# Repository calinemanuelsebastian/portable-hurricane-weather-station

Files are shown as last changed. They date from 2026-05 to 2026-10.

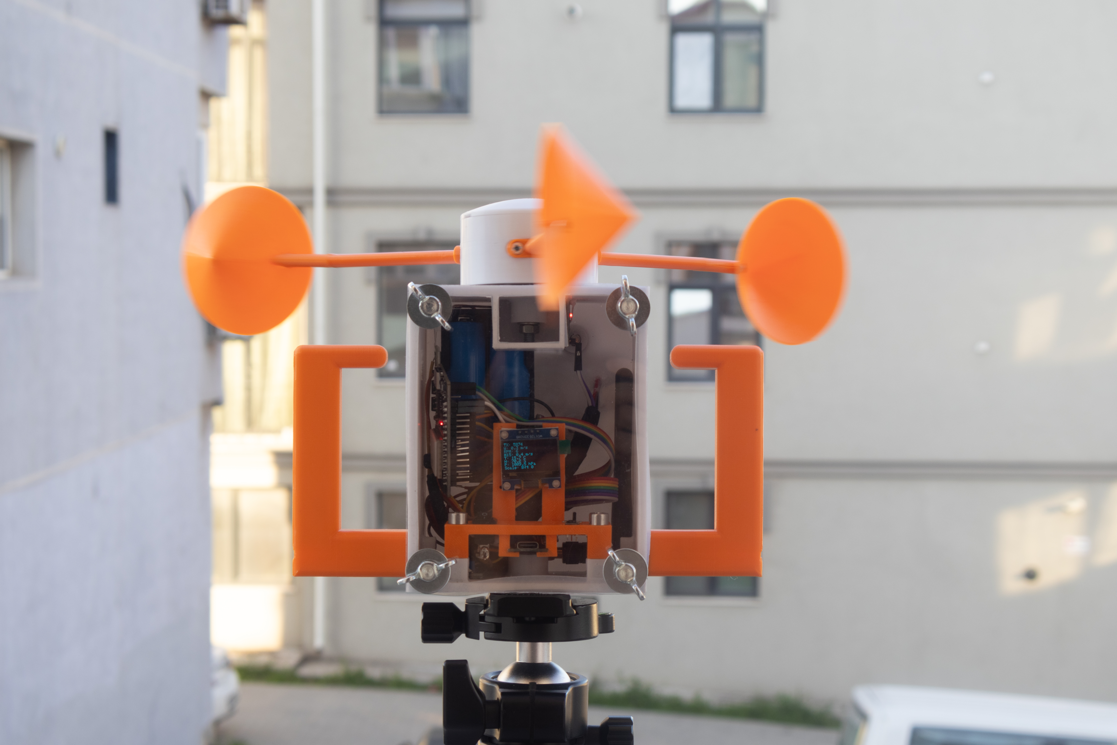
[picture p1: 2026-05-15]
images/IMG_7055-4.jpg

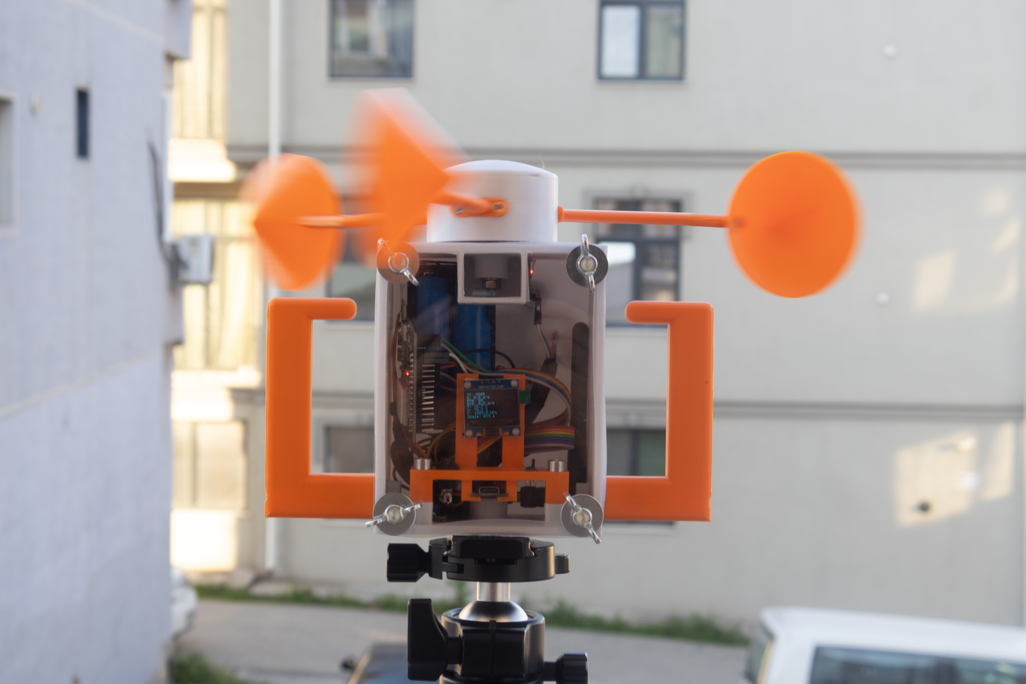
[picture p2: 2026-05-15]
images/IMG_7054-3.jpg

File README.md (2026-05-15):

# Portable Weather Station for Hurricane-Prone Island Environments

This repository contains the firmware, hardware documentation and development notes for a portable, low-cost meteorological monitoring system designed for local weather observation in hurricane-prone island environments.

The prototype measures wind speed, temperature, relative humidity and atmospheric pressure using an ESP32-based measurement unit, a custom Hall-effect cup anemometer, a DHT22 sensor and a BMP280 pressure sensor. Data are transmitted wirelessly to a central ESP32 station using nRF24L01 modules and published online through the ThingSpeak platform for remote visualisation.

## Links

Printables: https://www.printables.com/model/1719175-portable-esp32-weather-station-for-hurricane-prone 

ThingSpeak: https://thingspeak.mathworks.com/channels/3365147

## Project Status

This project is currently a functional prototype. The system has been tested for sensor acquisition, wireless transmission and online data publication. The wind-speed conversion algorithm is not callibrated against a reference anemometer.

## Main Features

- ESP32-based portable measurement unit
- Custom cup anemometer with Hall-effect pulse detection
- AHT22 temperature and relative humidity measurement
- BMP280 atmospheric pressure measurement
- nRF24L01 wireless communication between the portable unit and central station
- ESP32-based central station with Wi-Fi connection
- Online data publication through ThingSpeak
- OLED display for local data visualisation
- 3D-printed PETG enclosure and anemometer components

## System Architecture

The system is organised as follows:

```text
AHT20 + BMP280 + Hall-effect anemometer
                ↓
        ESP32 portable unit
                ↓
        nRF24L01 wireless link
                ↓
        ESP32 central station
                ↓
              Wi-Fi
                ↓
           ThingSpeak
                ↓
        Remote visualisation

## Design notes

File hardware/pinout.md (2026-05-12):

# Pinout

This document describes the wiring used by the current ESP32-based portable weather monitoring prototype.

The system has two electronic units:

1. `portable_station_esp32` – the measurement unit with sensors, OLED display, Hall-effect anemometer input and nRF24L01 transmitter;
2. `central_station_esp32` – the receiving unit with nRF24L01 receiver, Wi-Fi connection and ThingSpeak publication.

> Firmware reference: `portable_station_esp32_no_70kt_edge_filter.ino` and `central_station_esp32.ino`.

---

## 1. Portable station ESP32 pinout

### I2C bus

The portable station uses one I2C bus for the OLED display, AHT20 sensor and BMP280 pressure module.

| Function | ESP32 pin | Notes |
|---|---:|---|
| I2C SDA | GPIO 16 | Shared by OLED, AHT20 and BMP280 |
| I2C SCL | GPIO 17 | Shared by OLED, AHT20 and BMP280 |
| 3.3 V | 3V3 rail | Recommended supply for I2C modules |
| GND | GND | Common ground required |

Current I2C addresses used in the firmware:

| Device | Address | Notes |
|---|---:|---|
| AHT20 | `0x38` | Temperature and relative humidity |
| BMP280 | `0x77` | Change to `0x76` in firmware if the module uses that address |
| OLED display | `0x3C` | Change to `0x3D` in firmware if required |

Firmware line:

```cpp
Wire.begin(16, 17);
```

---

### AHT20 temperature and humidity sensor

| AHT20 pin | ESP32 / rail | Notes |
|---|---|---|
| VCC | 3.3 V | Use 3.3 V logic level with ESP32 |
| GND | GND | Common ground |
| SDA | GPIO 16 | I2C data |
| SCL | GPIO 17 | I2C clock |

---

### BMP280 pressure sensor

| BMP280 pin | ESP32 / rail | Notes |
|---|---|---|
| VCC / VIN | 3.3 V | Use 3.3 V if the board supports direct 3.3 V supply |
| GND | GND | Common ground |
| SDA | GPIO 16 | I2C data |
| SCL | GPIO 17 | I2C clock |

Current firmware address:

```cpp
#define BMP280_ADDRESS 0x77
```

If the sensor is not detected, try changing it to:

```cpp
#define BMP280_ADDRESS 0x76
```

---

### OLED display

| OLED pin | ESP32 / rail | Notes |
|---|---|---|
| VCC | 3.3 V | Use 3.3 V unless the OLED board specifically supports 5 V input |
| GND | GND | Common ground |
| SDA | GPIO 16 | I2C data |
| SCL | GPIO 17 | I2C clock |

Current firmware address:

```cpp
#define OLED_ADDRESS 0x3C
```

---

### KY-003 Hall-effect sensor for anemometer

The KY-003 Hall-effect sensor detects the three magnets installed on the rotating anemometer assembly.

| KY-003 pin | ESP32 / rail | Notes |
|---|---:|---|
| VCC | 3.3 V | Recommended for ESP32 logic safety |
| GND | GND | Common ground |
| OUT / Signal | GPIO 4 | Hall pulse input |

Firmware configuration:

```cpp
const int hallPin = 4;
pinMode(hallPin, INPUT_PULLUP);
attachInterrupt(digitalPinToInterrupt(hallPin), onMagnetDetected, FALLING);
```

Important notes:

- the firmware expects a falling edge when a magnet is detected;
- the current anemometer uses three magnets, so the firmware uses `pulsesPerRevolution = 3`;
- the current firmware uses only an electrical debounce gate for pulse filtering;
- no wind-speed-based 70 kt edge rejection threshold is used in the updated firmware.

---

### nRF24L01 module on portable station

| nRF24L01 pin | ESP32 pin / rail | Notes |
|---|---:|---|
| VCC | 3.3 V | Do not power the nRF24L01 from 5 V |
| GND | GND | Common ground |
| CE | GPIO 22 | Radio control pin |
| CSN / CS | GPIO 5 | SPI chip select |
| SCK | GPIO 18 | SPI clock |
| MISO | GPIO 19 | SPI MISO |
| MOSI | GPIO 23 | SPI MOSI |
| IRQ | Not connected | Not used in the current firmware |

Firmware configuration:

```cpp
#define CE_PIN    22
#define CSN_PIN    5
#define SCK_PIN   18
#define MISO_PIN  19
#define MOSI_PIN  23

SPI.begin(SCK_PIN, MISO_PIN, MOSI_PIN, CSN_PIN);
RF24 radio(CE_PIN, CSN_PIN);
const byte pipeAddress[6] = "RxAAA";
```

Power recommendation:

- place a capacitor of approximately 10 µF to 100 µF across the nRF24L01 VCC and GND pins;
- keep radio wiring short;
- use a stable 3.3 V supply, especially when the ESP32 and radio transmit at the same time.

---

## 2. Central station ESP32 pinout

The central station currently uses an ESP32 board, one nRF24L01 module, Wi-Fi and ThingSpeak publication. It does not use local environmental sensors in the current firmware.

### nRF24L01 module on central station

| nRF24L01 pin | ESP32 pin / rail | Notes |
|---|---:|---|
| VCC | 3.3 V | Do not power the nRF24L01 from 5 V |
| GND | GND | Common ground |
| CE | GPIO 22 | Radio control pin |
| CSN / CS | GPIO 5 | SPI chip select |
| SCK | GPIO 18 | SPI clock |
| MISO | GPIO 19 | SPI MISO |
| MOSI | GPIO 23 | SPI MOSI |
| IRQ | Not connected | Not used in the current firmware |

Firmware configuration:

```cpp
#define CE_PIN   22
#define CSN_PIN   5
#define SCK_PIN  18
#define MISO_PIN 19
#define MOSI_PIN 23

SPI.begin(SCK_PIN, MISO_PIN, MOSI_PIN, CSN_PIN);
RF24 radio(CE_PIN, CSN_PIN);
const byte pipeAddress[6] = "RxAAA";
```

---

## 3. Shared radio configuration

Both ESP32 boards must use the same nRF24L01 communication settings.

| Setting | Current value |
|---|---:|
| Pipe address | `RxAAA` |
| Data rate | `RF24_250KBPS` |
| Payload size | 32 bytes |
| Packet magic | `0x574E4431UL` / `WND1` |
| Packet version | `1` |

The packet structure must remain identical in both firmware files.

Current packet fields:

```cpp
struct __attribute__((packed)) SensorPacket {
  uint32_t magic;
  uint8_t  version;
  uint8_t  reserved;
  uint16_t seq;

  float temperatureC;
  float humidityPct;
  float seaLevelHpa;

  float windInstantMps;
  float windMeanMps;
  float windPeakMps;
};
```

The firmware checks that the payload is exactly 32 bytes:

```cpp
static_assert(sizeof(SensorPacket) == 32, "SensorPacket must be exactly 32 bytes");
```

If new fields are added, the packet size must be checked carefully because the nRF24L01 maximum payload size is 32 bytes.

---

## 4. ThingSpeak field mapping

The receiver firmware currently uploads the received values to ThingSpeak using the following field order:

| ThingSpeak field | Data uploaded by receiver firmware | Unit / meaning |
|---:|---|---|
| Field 1 | `temperatureC` | Temperature in °C |
| Field 2 | `humidityPct` | Relative humidity in % |
| Field 3 | `seaLevelHpa` | Sea-level equivalent pressure in hPa |
| Field 4 | `windInstantMps` | Instantaneous / displayed wind speed in m/s |
| Field 5 | `windMeanMps` | Mean wind speed over the transmission interval in m/s |
| Field 6 | `windPeakMps` | Peak / gust wind speed over the transmission interval in m/s |
| Field 7 | `beaufortMean` | Beaufort number calculated from mean wind speed |
| Field 8 | `sshwsEqMean` | Saffir-Simpson equivalent category calculated from mean wind speed |

Receiver firmware lines:

```cpp
ThingSpeak.setField(1, p.temperatureC);
ThingSpeak.setField(2, p.humidityPct);
ThingSpeak.setField(3, p.seaLevelHpa);
ThingSpeak.setField(4, p.windInstantMps);
ThingSpeak.setField(5, p.windMeanMps);
ThingSpeak.setField(6, p.windPeakMps);
ThingSpeak.setField(7, (long)beaufortMean);
ThingSpeak.setField(8, (long)sshwsEqMean);
```

Important: the ThingSpeak channel labels should match this field order. If the online channel is labelled differently, either relabel the ThingSpeak fields or change the receiver firmware field mapping.

---

## 5. Power wiring notes

### Portable station

The portable station is powered from two 18650 lithium-ion cells connected in series and protected by a 2S BMS.

Recommended power arrangement:

| Rail / module | Purpose |
|---|---|
| 2 × 18650 cells in series | Main battery pack |
| 2S BMS | Battery protection |
| Main switch | Turns portable unit on and off |
| MP1584EN buck converter | Regulated 3.3 V rail for sensors and nRF24L01 |
| MT3608 boost converter | 5 V supply for ESP32 development board, if used in the current build |

Important safety notes:

- verify all voltages with a multimeter before connecting the ESP32, sensors or radio modules;
- all modules must share a common ground;
- do not connect 5 V signals to ESP32 GPIO pins;
- the nRF24L01 must be powered from 3.3 V, not 5 V;
- lithium-ion cells require careful handling, correct polarity and a suitable BMS/charging arrangement.

### Central station

The central station can be powered from USB or a stable 5 V supply suitable for the ESP32 development board. The nRF24L01 module must still be supplied from 3.3 V.

---

## 6. Quick wiring checklist

Before powering the system:

- check battery polarity;
- check 3.3 V and 5 V rails with a multimeter;
- check that all grounds are connected together;
- check that the nRF24L01 modules receive 3.3 V only;
- check that SDA and SCL are connected to GPIO 16 and GPIO 17 on the portable station;
- check that both nRF24L01 modules use the same CE, CSN, SCK, MISO and MOSI wiring;
- check that the KY-003 output is connected to GPIO 4;
- check that the ThingSpeak field labels match the receiver firmware mapping;
- check that the packet structure is identical in both firmware files.

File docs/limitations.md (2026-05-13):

# Limitations

## Prototype status

This project is currently a functional prototype. It has been developed to demonstrate local meteorological data acquisition, wireless transmission and online visualisation. It is not a certified meteorological instrument and should not be used as a replacement for official weather stations.

## Wind-speed accuracy

The anemometer uses a custom mechanical design and a Hall-effect pulse detection system. The current wind-speed conversion algorithm is provisional and has not yet been calibrated against a reference anemometer.

Main limitations:

- the calibration factor is still experimental;
- rotor geometry affects the wind-speed conversion;
- friction, bearing quality and rotor balance may influence measurements;
- low wind speeds may be affected by starting friction;
- strong gusts may require further testing;
- the current algorithm requires calibration and characterisation under controlled conditions;
- the firmware currently uses an electrical debounce gate for Hall-sensor pulse detection, but no wind-speed-based edge rejection threshold is applied.

## Sensor limitations

The AHT20 and BMP280 sensors are suitable for prototype-level environmental monitoring, but the readings may be affected by enclosure placement, direct sunlight, ventilation and thermal influence from nearby electronics.

Possible sources of error include:

- insufficient airflow around the temperature and humidity sensor;
- heating from the ESP32 or voltage regulators;
- lack of radiation shielding;
- pressure reduction errors if altitude is not set correctly;
- sensor drift over time.

## Pressure correction limitations

The firmware converts pressure readings to sea-level equivalent pressure using a configured altitude value. If the altitude value is incorrect or left unchanged for a different deployment location, the reported sea-level pressure may be inaccurate.

For more reliable pressure reporting, future versions should:

- set the deployment altitude accurately;
- document the altitude used during each test;
- compare pressure readings with a reference instrument;
- allow altitude configuration without modifying the firmware.

## Enclosure limitations

The enclosure is made from 3D-printed PETG and uses a plexiglass front panel with a silicone gasket. Component ingresses are sealed with hot-melt adhesive.

This provides basic prototype-level protection, but the enclosure is not formally IP-rated.

Further improvements are needed for:

- long-term rain exposure;
- salt-air environments;
- UV exposure;
- corrosion protection;
- cable gland sealing;
- mechanical impact resistance;
- hurricane-level wind and debris conditions.

## Communication limitations

The current version uses nRF24L01 modules for communication between the portable station and the central station.

Limitations include:

- limited range compared with LoRa-based solutions;
- possible interference in the 2.4 GHz band;
- reduced performance through walls or obstacles;
- dependency on correct antenna positioning;
- possible packet loss in unfavourable conditions;
- no quantified packet-loss, range or reliability measurements have been performed yet;
- the transmitted packet is currently designed to fit within the nRF24L01 payload limit, so future changes to the packet structure should be checked carefully.

Future versions may use SX1278 LoRa modules or ESP32 boards equipped with LoRa transceivers for improved range and robustness.

## Power limitations

The portable unit uses two 18650 lithium-ion cells. Battery autonomy has not yet been fully tested under long-term outdoor operation.

The current documented wiring also includes a dedicated switch between the BMS/power distribution output and the input of the 3.3 V DC-DC converter. This allows the 3.3 V peripheral rail to be switched independently, but it also requires careful operation if the ESP32 5 V supply remains active.

Power-related limitations include:

- unknown long-term battery life;
- reduced capacity in cold or harsh conditions;
- possible voltage drops under load;
- charging system requiring further testing;
- lack of integrated solar charging in the current version;
- possible unintended back-powering of peripheral modules if the ESP32 is powered while the switched 3.3 V rail is off.

## Online publication limitations

The central station depends on Wi-Fi access and the availability of the ThingSpeak platform. If internet connectivity is lost, online visualisation may be interrupted.

Possible limitations include:

- dependency on Wi-Fi coverage at the central station;
- dependency on the ThingSpeak platform;
- interruption of online visualisation during internet outages;
- possible mismatch between firmware field order and ThingSpeak channel labels if the channel is not configured consistently.

Possible improvements include:

- local data logging;
- offline storage during internet outages;
- automatic upload after reconnection;
- configurable update intervals;
- alert thresholds for dangerous wind speeds or pressure drops.

## Testing limitations

The current tests focused on functional operation, not on formal validation.

The prototype has been tested for:

- sensor reading;
- OLED display;
- Hall sensor pulse detection;
- wireless transmission;
- reception by the central station;
- online publication through ThingSpeak.

The prototype has not yet been fully tested for:

- calibrated measurement accuracy;
- long-term outdoor reliability;
- battery autonomy;
- communication range;
- packet-loss rate;
- operation during heavy rain;
- resistance to severe wind;
- salt-air exposure;
- actual hurricane conditions.

## Intended use

The system is intended for:

- educational use;
- prototype development;
- experimental local weather observation;
- community-level awareness;
- research and demonstration purposes.

The system is not intended for:

- official meteorological reporting;
- navigation safety decisions;
- emergency warnings without independent verification;
- certified disaster-response operations.

## Future improvements

Recommended future developments include:

- calibration against a reference anemometer;
- comparison with certified temperature, humidity and pressure sensors;
- improved enclosure sealing;
- solar charging;
- longer-range communication;
- local data storage;
- improved power management;
- better radiation shielding for the temperature and humidity sensor;

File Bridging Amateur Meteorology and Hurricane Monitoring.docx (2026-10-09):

BRIDGING AMATEUR METEOROLOGY AND HURRICANE MONITORING: A PORTABLE WEATHER MONITORING SYSTEM FOR ISLAND COMMUNITIES

Emanuel-Sebastian CĂLIN

Constanța Maritime University

Coordinator: Lecturer PhD Alina Lucia BOȘTINĂ

Constanța Maritime University

Abstract

Hurricanes are extreme meteorological events with significant consequences for island communities, where geographical isolation, exposure to strong winds, and infrastructure vulnerability can intensify their social and operational impacts. In this context, real-time local weather monitoring can support preparedness, situational awareness, and emergency response. This study presents the design, implementation, and functional evaluation of a portable, low-cost meteorological monitoring system intended for hurricane-prone island environments. The prototype measures wind speed, temperature, relative humidity, and atmospheric pressure using a Hall sensor-based cup anemometer and an integrated AHT20 + BMP280 sensor module. The collected data are transmitted wirelessly to a central station and published online through the ThingSpeak platform, enabling remote access and visualisation. The system architecture, operating principles, and communication flow are described to show how localised meteorological data can be acquired and made available remotely. Functional tests confirmed the prototype's ability to collect, transmit, and publish meteorological data, indicating its potential as a complementary tool for local weather observation in areas exposed to severe weather events.

Keywords: hurricane-prone islands; disaster preparedness; portable weather station; low-cost meteorological instrumentation; remote data visualisation.

1. Introduction

Tropical cyclones (TCs), referred to as hurricanes in the Atlantic and eastern North Pacific basins, are among the most destructive meteorological hazards, affecting millions of people worldwide each year (1, 2). In these basins, a tropical cyclone is classified as a hurricane when its maximum sustained winds reach at least 64 knots, equivalent to approximately 119 km/h or 74 mph (3). Hurricane intensity is commonly described using the Saffir-Simpson Hurricane Wind Scale, which relates wind-speed categories to the potential for property damage and infrastructure disruption (4). Beyond extreme winds, tropical cyclones are multi-hazard events that may produce torrential rainfall, storm surges, flooding, and occasionally tornadoes, generating complex impacts on natural and human systems (2).

Island areas are particularly exposed to the effects of hurricanes because geographical isolation, limited land area, and dependence on critical infrastructure can increase vulnerability. Ports, airports, coastal roads, electricity networks, and communication systems are essential for evacuation, emergency response, and recovery, but they may also be severely affected during extreme weather events. In small island contexts, damage to a limited number of critical assets can disrupt emergency coordination and post-event recovery (8, 9).

Meteorological observation is a key component of early warning systems. The World Meteorological Organization identifies detection, monitoring, analysis, and forecasting as essential elements of effective multi-hazard early warning, together with risk knowledge, warning dissemination, and preparedness to respond (5). At the global scale, observing systems support weather analyses, forecasts, advisories, warnings, and climate monitoring (6). However, in isolated or resource-limited island environments, local observations may be spatially sparse or difficult to maintain, especially during severe weather events.

The atmospheric parameters selected for monitoring in this study are directly relevant to hurricane-prone environments. Wind speed is one of the defining characteristics of hurricane intensity and is essential for evaluating hazardous wind conditions. Atmospheric pressure variations may indicate the approach or development of low-pressure weather systems, while temperature and relative humidity contribute to the characterisation of local atmospheric conditions. These variables are consistent with WMO guidance on meteorological observation, including air temperature, atmospheric pressure, humidity, surface wind, and automatic weather stations (7).

Recent developments in embedded systems, wireless communication, and Internet of Things technologies have enabled compact and affordable weather stations for real-time environmental monitoring. Such systems do not replace certified meteorological stations, but they can provide useful supplementary observations for educational, research, community-based, or temporary field applications (10). In this context, the term amateur meteorology refers to non-certified, community-oriented, and low-cost observation activities that can complement, but not replace, official meteorological infrastructure. In this context, amateur meteorology refers to non-certified, community-oriented, and low-cost observation activities that can complement, but not replace, official meteorological infrastructure.

The aim of this paper is to present and functionally evaluate a portable, low-cost meteorological monitoring system designed to complement local weather observations and support situational awareness in hurricane-prone island environments.

2. Monitoring Needs in Hurricane-Prone Island Environments

Hurricane-prone island environments require monitoring approaches capable of providing timely, localised, and accessible meteorological information. The IPCC reports that small islands are increasingly affected by tropical cyclones, storm surges, heavy precipitation, sea-level rise, and related impacts across natural and human systems (8). Studies on Small Island Developing States also show that disaster vulnerability results from the interaction between physical exposure and local social, economic, and institutional conditions (9).

Although global and national observing networks provide indispensable information for forecasting and warning (5, 6, 7), local observations may be sparse in isolated or underserved areas, especially in small island contexts where exposure, remoteness, and infrastructure limitations increase vulnerability (8, 9). During severe weather events, permanent monitoring infrastructure may also be affected by power outages, communication disruptions, flooding, corrosion, or physical damage (5, 8, 9). Complementary local monitoring systems can therefore add practical value by increasing the number of observation points in vulnerable or underserved locations (5, 10).

For a local monitoring system to be useful, it should acquire relevant atmospheric variables and make them available to users without requiring direct access to the instrument. Wind speed, atmospheric pressure, temperature, and relative humidity provide a basic but important picture of the local atmospheric state and are among the standard variables considered in meteorological observation practice (7). Remote visualisation further supports situational awareness because users can observe changing conditions from a safer or more centralised location, which is consistent with the role of timely observation and communication in early warning systems and IoT-based monitoring approaches (5, 10).

In this paper, this monitoring need is addressed through a portable weather station designed to acquire wind speed, temperature, relative humidity, and atmospheric pressure data and publish them online. The system is intended as a complementary observation tool rather than an official source for warnings, certified measurements, or safety-critical decisions.

3. Design and Implementation of the Portable Weather Station

The proposed system was designed as a two-node architecture consisting of a portable measurement unit and a central receiving station. The measurement unit acquires local meteorological data, while the central station receives the data through a wireless link and publishes them online. The general data flow is presented in Figure 1.
Sensors
ESP32 (transmitter)
nRF24L01
ESP32 (receiver)
ThingSpeak

Figure 1. General architecture of the portable meteorological monitoring system

The portable unit is controlled by an ESP32 development board, selected because it provides sufficient processing capability for sensor reading, pulse counting, local display, and wireless communication in a compact format. In the documented prototype configuration, temperature and relative humidity are acquired using an AHT20 sensor, while atmospheric pressure is measured using a BMP280 module. The measured values are also shown on a small OLED display, which allows direct verification during testing and deployment.

Wind speed is measured using a custom cup anemometer. The rotating assembly includes three neodymium magnets placed at a constant distance from the centre of the shaft, while a KY-003 Hall-effect sensor module is fixed nearby. When the cups rotate, each magnet passes in front of the Hall sensor and generates a digital pulse. The ESP32 counts these pulses during the sampling interval and converts pulse frequency into a wind-speed value. At firmware level, the pulse frequency is converted into rotor speed using the configured number of pulses per revolution, after which the anemometer circumference and a provisional calibration factor are used to estimate wind speed. Since the relationship between rotor speed and actual wind speed depends on the anemometer geometry, the conversion algorithm is treated as a provisional functional implementation and requires calibration against a reference anemometer according to accepted meteorological measurement practice (7).

Wireless communication between the portable unit and the central station is currently implemented using nRF24L01 radio modules. The measurement unit sends the acquired values as data packets, while the receiving ESP32 decodes the information and prepares it for online publication. This communication solution was selected for the functional prototype because it is compact, low-cost, and suitable for short-range wireless data transmission, which is consistent with the use of low-cost components in IoT-based weather station prototypes (10). Future versions could use SX1278 LoRa modules or ESP32 boards equipped with LoRa transceivers where longer communication range is required.

The central station is built around a second ESP32 board connected to Wi-Fi. After receiving the values from the portable unit, it publishes the data to a dedicated ThingSpeak channel using the platform API. In the tested firmware, measurements were published at 15 s intervals, which was sufficient for remote visualisation during the functional evaluation. This arrangement separates local measurement from internet publication, allowing the portable station to be placed in the monitored area while the central station manages Wi-Fi connectivity and online data visualisation.

The portable unit is powered by two 18650 lithium-ion cells connected in series and protected by a battery management module. DC-DC converters provide the voltage levels required by the electronic modules, including a 3.3 V rail for low-voltage components and a 5 V line for the ESP32 development board. The enclosure, anemometer arms, and hub were manufactured using 3D-printed PETG parts. The front panel is made of plexiglass and fitted with a silicone gasket, while a second silicone gasket is placed between the external sensor pod and the main case to improve sealing at this interface. Cable and component ingresses were sealed using hot-melt adhesive for prototype-level protection. The modular structure of the system also allows future adaptation for different monitoring objectives by changing or extending the sensor set, communication module, or enclosure design without modifying the general architecture of the prototype.

4. Functional Evaluation and Results

The prototype was evaluated through functional tests intended to verify the complete data chain, from local measurement to online visualisation. The purpose of this stage was not to perform metrological calibration against certified instruments, but to confirm that the system can acquire data from the sensors, process the anemometer pulses, transmit the measurements wirelessly, and publish the results online. Formal meteorological measurement quality requires calibration, documented observing methods, and comparison with appropriate reference instruments (7).

During testing, the portable unit was powered from the 18650 battery pack and the measured values were displayed locally on the OLED screen. The AHT20 sensor was used to acquire temperature and relative humidity, while the BMP280 module provided pressure readings, which were converted in the firmware to sea-level equivalent pressure using a hard-coded altitude value. The cup anemometer was checked by rotating the rotor and observing the response of the Hall-effect sensor. Each passage of the magnets in front of the KY-003 module generated pulses that were counted by the ESP32 and converted by the software into a provisional wind-speed value.

The wireless communication link was tested using the nRF24L01 modules installed on the portable unit and on the central station. The measurement unit transmitted data packets containing the acquired meteorological values, while the receiving ESP32 decoded the information and forwarded it through Wi-Fi to the dedicated ThingSpeak channel. The online interface displayed separate charts for relative humidity, temperature, sea-level pressure, and wind speed, confirming that the measured data could be accessed remotely, as shown in Figure 2.

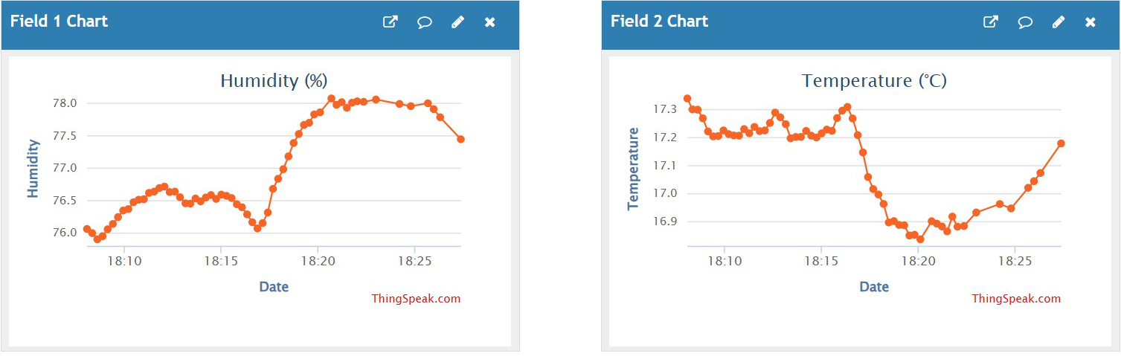
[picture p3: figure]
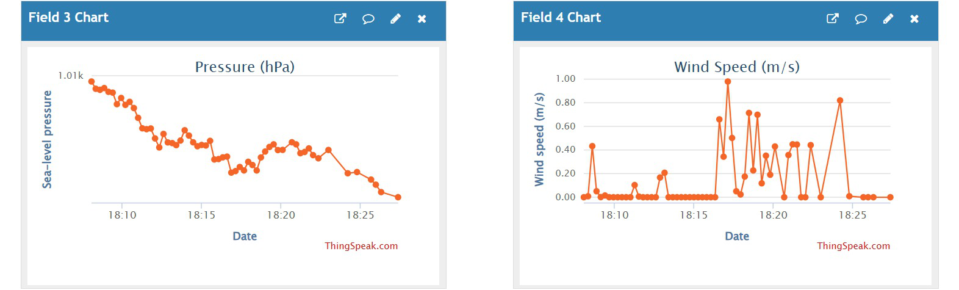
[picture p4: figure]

Figure 2. ThingSpeak dashboard during functional testing

The results confirm the functional operation of the prototype as an integrated portable weather station. The system was able to collect meteorological data, transmit them from the portable unit to the central station, and publish them online at 15s intervals during testing. The local OLED display also allowed direct monitoring of the measured values during operation, which is useful during testing and field deployment. Since the evaluation did not include comparison with calibrated reference instruments, numerical accuracy indicators such as measurement error, uncertainty, or deviation from reference values are not reported at this stage.

Several limitations were identified during this stage. First, the wind-speed conversion method has not yet been calibrated against a reference anemometer. The pressure correction also depends on the accuracy of the altitude value used in the firmware. Secondly, the tests focused on functional operation rather than long-term reliability, communication range, battery autonomy, or resistance to severe outdoor conditions. Although the PETG enclosure, plexiglass front panel, silicone gasket, and sealed ingresses provide adequate levels of protection, further improvements would be required before deployment in harsh hurricane-prone island environments, where exposure to extreme weather and infrastructure vulnerability are important concerns (8, 9).

5. Conclusions and Future Developments

This paper presented the design, implementation, and functional evaluation of a portable meteorological monitoring system intended for hurricane-prone island environments. The prototype was developed as a low-cost weather station capable of measuring wind speed, temperature, relative humidity, and atmospheric pressure. The system combines an ESP32-based measurement unit, a custom Hall-effect cup anemometer, an AHT20 + BMP280 sensor configuration, wireless transmission through nRF24L01 modules, and an ESP32-based central station connected to ThingSpeak for remote data visualisation.

The functional evaluation confirmed that the prototype can acquire meteorological data, display the values locally, transmit them wirelessly to the central station, and publish them online. These results demonstrate the correct operation of the main data chain, from sensor acquisition to remote visualisation. In this form, the system can be considered a practical complementary tool for local weather observation, especially in areas where permanent meteorological infrastructure is limited, difficult to access, or vulnerable during severe weather events (5, 8, 9).

At the same time, the prototype should not be regarded as a replacement for certified meteorological stations, since the current tests focused on functional operation rather than metrological accuracy, long-term reliability, or performance under extreme environmental conditions (7). In particular, the wind-speed measurement algorithm requires calibration against a reference anemometer, and the temperature, humidity, and pressure readings should be compared with reference instruments.

Future developments will focus on improving measurement performance, mechanical robustness, autonomy, and communication range. The wind-speed measurement system could be improved through a more rigid and better aligned shaft assembly, lower-friction bearings, improved rotor balancing, more precise magnet positioning, and calibration against a reference anemometer. The enclosure could also be improved through better sealing, corrosion-resistant connectors, cable glands, and extended outdoor testing under rain, salt-air, wind, and temperature variations.

The same modular platform could also be adapted for additional sensing applications. Depending on the use case, future versions could integrate air-quality sensors, ultraviolet radiation sensors, rain detection or rainfall measurement, soil-moisture sensors, battery-voltage monitoring, local data storage, or configurable alert thresholds. These extensions would allow the prototype to be used not only for hurricane-related monitoring, but also for broader environmental observation, educational fieldwork, temporary deployments, agricultural monitoring, or community-level situational awareness.

Although the prototype was developed for hurricane-prone island environments, the same communication concept could be extended to other isolated or difficult-to-access locations, such as remote maritime worksites, offshore facilities, natural or artificial islands, temporary field stations, or areas where direct access to main land-based infrastructure is limited. In such scenarios, longer-range radio modules such as SX1278, SX1262, or RFM96, possibly combined with intermediate relay nodes, would be more suitable than the short-range nRF24L01 link used in the current prototype.

Acknowledgements

The author would like to express sincere gratitude to Lecturer Alina Lucia BOȘTINĂ, PhD, for her guidance, support, and valuable feedback during the development of this paper and prototype. The author also thanks Diana-Iuliana MANEA, Lecturer Voicu Nicolae GROȘAN, PhD, and Marin OPREA, PhD, for their technical advice, encouragement, and support during the design, testing, and documentation of the portable weather monitoring system.

Project materials

The firmware, documentation, and 3D-printable parts are available through the project repository: https://github.com/calinemanuelsebastian/portable-hurricane-weather-station.

Bibliography

1. Geiger, T., Frieler, K. and Bresch, D. N. (2018), A global historical data set of tropical cyclone exposure (TCE-DAT), in „Earth System Science Data”, volume 10, issue 1, pp. 185-194, DOI: 10.5194/essd-10-185-2018.

2. World Meteorological Organization (2023), Tropical cyclones and their related hazards, Fact Sheet.

3. National Ocean Service, National Oceanic and Atmospheric Administration (n.d.), What is a hurricane?.

4. National Hurricane Center, National Oceanic and Atmospheric Administration (n.d.), Saffir-Simpson Hurricane Wind Scale.

5. World Meteorological Organization (2018), Multi-hazard Early Warning Systems: A Checklist, Outcome of the first Multi-hazard Early Warning Conference.

6. World Meteorological Organization (n.d.), Global Observing System (GOS).

7. World Meteorological Organization (2024), Guide to Instruments and Methods of Observation (WMO-No. 8), 2024 edition.

8. Mycoo, M., Wairiu, M., Campbell, D., Duvat, V., Golbuu, Y., Maharaj, S., Nalau, J., Nunn, P., Pinnegar, J. and Warrick, O. (2022), Small Islands, in „Climate Change 2022: Impacts, Adaptation and Vulnerability”, Contribution of Working Group II to the Sixth Assessment Report of the Intergovernmental Panel on Climate Change, Cambridge, Cambridge University Press.

9. Pelling, M. and Uitto, J. I. (2001), Small island developing states: natural disaster vulnerability and global change, in „Global Environmental Change Part B: Environmental Hazards”, 3(2), pag. 49-62, DOI: 10.1016/S1464-2867(01)00018-3.

10. Ioannou, K., Karampatzakis, D., Amanatidis, P., Aggelopoulos, V. and Karmiris, I. (2021), Low-cost automatic weather stations in the Internet of Things, in „Information”, 12(4), 146, DOI: 10.3390/info12040146.

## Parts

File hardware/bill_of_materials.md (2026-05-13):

# Bill of Materials

This bill of materials covers the current functional prototype of the portable ESP32-based weather monitoring system. The system consists of two main units:

1. **portable_station_esp32** — the portable measurement unit;
2. **central_station_esp32** — the receiving station connected to Wi-Fi and ThingSpeak.

> Note: the current firmware uses an **AHT20 + BMP280** configuration. If the physical module is changed, the firmware, documentation and ThingSpeak labels should be updated accordingly.

---

## 1. Control and communication components

### ESP32 development board
- **Quantity:** 2
- **Used for:** portable measurement unit and central receiving station
- **Notes:** one ESP32 reads the sensors and transmits data; the second ESP32 receives the data and publishes them online.

### nRF24L01 wireless module
- **Quantity:** 2
- **Used for:** wireless communication between the portable unit and the central station
- **Notes:** used in the current functional prototype.

### SX1278 LoRa module
- **Quantity:** 2
- **Status:** optional / future improvement
- **Notes:** may be used in future versions where longer communication range is required.

### ESP32 board with integrated LoRa transceiver
- **Quantity:** 2
- **Status:** optional / alternative configuration
- **Notes:** may be used in future versions to simplify the long-range communication architecture.

---

## 2. Sensors and display

### AHT20 sensor module
- **Quantity:** 1
- **Used for:** temperature and relative humidity measurement
- **Notes:** connected to the portable ESP32 through the I2C bus.

### BMP280 module
- **Quantity:** 1
- **Used for:** atmospheric pressure measurement
- **Notes:** connected to the portable ESP32 through the I2C bus. The firmware can use address `0x77` or `0x76`, depending on the physical module.

### KY-003 Hall-effect sensor module
- **Quantity:** 1
- **Used for:** anemometer pulse detection
- **Notes:** detects the passage of the magnets mounted on the rotating anemometer assembly.

### OLED display
- **Quantity:** 1
- **Used for:** local visualisation on the portable unit
- **Notes:** displays temperature, humidity, pressure, wind speed and system status information.

---

## 3. Anemometer assembly

### Neodymium magnets
- **Quantity:** 3
- **Used for:** Hall-effect pulse generation
- **Notes:** mounted on the rotating anemometer assembly. The firmware is currently configured for three pulses per revolution.

### 625 bearings
- **Quantity:** 2
- **Used for:** anemometer shaft support
- **Notes:** open bearings are preferred. In the prototype, 625ZZ bearings may be modified by removing the metal shields and cleaning the grease to reduce rotational resistance.

### M5 threaded rod or M5 screw
- **Quantity:** 1
- **Used for:** anemometer shaft assembly
- **Notes:** cut to the length required by the printed anemometer structure.

### PETG printed anemometer parts
- **Quantity:** several
- **Used for:** anemometer hub, arms and cup supports
- **Notes:** printed from PETG for better mechanical and environmental resistance than PLA.

---

## 4. Power supply components

### 18650 lithium-ion cells
- **Quantity:** 2
- **Used for:** portable unit power supply
- **Notes:** connected in series as a 2S battery pack.

### 2S BMS module
- **Quantity:** 1
- **Used for:** battery protection
- **Notes:** protects the two 18650 cells connected in series.

### Main power switch
- **Quantity:** 1
- **Used for:** main portable-station power control, if installed immediately after the BMS output
- **Notes:** use this switch to disconnect the complete portable unit from the battery supply if a full master on/off function is required.

### 3.3 V rail switch
- **Quantity:** 1
- **Used for:** switching the input of the 3.3 V DC-DC converter
- **Notes:** in the current documented wiring, this switch is placed between the BMS/power distribution positive output and the MP1584EN input. It controls the 3.3 V rail used by the AHT20, BMP280, OLED display, KY-003 Hall sensor and nRF24L01 module.

### MP1584EN step-down converter
- **Quantity:** 1
- **Used for:** regulated 3.3 V supply
- **Notes:** supplies low-voltage modules such as the AHT20, BMP280, OLED display, KY-003 and nRF24L01. Verify the output with a multimeter before connecting the modules.

### 5 V regulator / boost converter
- **Quantity:** 1
- **Used for:** 5 V ESP32 development-board supply, if the ESP32 is powered through VIN/5V
- **Notes:** choose a regulator suitable for the 2S lithium-ion input range. A fully charged 2S pack can reach approximately 8.4 V.

### Additional DC-DC converters
- **Quantity:** as required
- **Status:** optional
- **Notes:** useful for alternative power architectures, separate rails or charging experiments.

### USB cable / USB power adapter
- **Quantity:** as required
- **Used for:** programming and powering the ESP32 boards
- **Notes:** especially useful for the central receiving station.

### Solar charging module
- **Quantity:** 1
- **Status:** optional / future improvement
- **Notes:** may improve autonomy during outdoor deployment.

---

## 5. Enclosure and printed parts

### PETG printed enclosure
- **Quantity:** 1 complete set
- **Used for:** housing the portable measurement unit
- **Notes:** includes the main enclosure body and any internal supports.

### PETG printed internal supports
- **Quantity:** several
- **Used for:** mounting electronic modules inside the enclosure
- **Notes:** quantity depends on the final internal layout.

### PETG filament
- **Quantity:** approximately 1 kg
- **Used for:** printing the enclosure, hub, arms and supports
- **Notes:** required if the parts are printed locally.

### Plexiglass sheet
- **Quantity:** 1
- **Used for:** front panel
- **Notes:** allows visibility of the OLED display and internal layout.

### Silicone gasket material
- **Quantity:** 1
- **Used for:** front panel sealing
- **Notes:** placed between the plexiglass panel and the printed enclosure.

### Weatherproof cable glands
- **Quantity:** as required
- **Status:** optional / future improvement
- **Notes:** recommended for more robust outdoor use.

---

## 6. Mechanical fasteners and assembly hardware

### Threaded inserts
- **Quantity:** as required
- **Used for:** printed enclosure and mechanical fixing points
- **Notes:** use the sizes required by the final printed design.

### Screws, nuts and washers
- **Quantity:** as required
- **Used for:** enclosure, front panel, supports and anemometer assembly
- **Notes:** stainless steel or corrosion-resistant fasteners are recommended for humid or salt-air environments.

### Butterfly screws and wide washers
- **Quantity:** as required
- **Used for:** removable access points, such as the plexiglass front panel
- **Notes:** useful where repeated access to the internal electronics is needed.

---

## 7. Wiring and electrical assembly materials

### Wires and connectors
- **Quantity:** as required
- **Used for:** electrical connections
- **Notes:** Dupont wires, soldered wires, JST connectors or similar may be used. Soldered or locking connectors are preferred for field use.

### Header pins
- **Quantity:** as required
- **Used for:** module connections
- **Notes:** useful for ESP32, sensor modules and radio modules.

### Prototype PCB / perfboard
- **Quantity:** as required
- **Status:** optional
- **Notes:** useful for making the internal wiring cleaner and more reliable.

### Heat-shrink tubing
- **Quantity:** as required
- **Used for:** insulation and strain relief
- **Notes:** recommended for soldered joints and exposed conductors.

### Capacitor for nRF24L01 module
- **Quantity:** 1–2
- **Recommended value:** 10 µF to 100 µF
- **Used for:** stabilising the nRF24L01 power supply
- **Notes:** place the capacitor close to the nRF24L01 VCC and GND pins.

---

## 8. Adhesives, sealants and auxiliary materials

### Threadlocker, e.g. Loctite
- **Quantity:** as required
- **Used for:** preventing loosening of nuts and screws caused by vibration or rotation.

### Double-sided adhesive tape
- **Quantity:** as required
- **Used for:** temporary or semi-permanent mounting of lightweight internal components.

### Hot-melt adhesive or sealant
- **Quantity:** as required
- **Used for:** prototype-level sealing of cable and component ingresses.

### Silicone sealant
- **Quantity:** optional
- **Status:** future improvement
- **Notes:** may provide better sealing than hot-melt adhesive for outdoor use.

---

## 9. Optional data and autonomy improvements

### MicroSD card module
- **Quantity:** 1
- **Status:** optional / future improvement
- **Purpose:** local data logging during internet outages.

### Real-time clock module
- **Quantity:** 1
- **Status:** optional / future improvement
- **Purpose:** timestamping locally stored measurements.

### Battery voltage monitoring circuit
- **Quantity:** 1
- **Status:** optional / future improvement
- **Purpose:** monitoring battery level and improving power management.

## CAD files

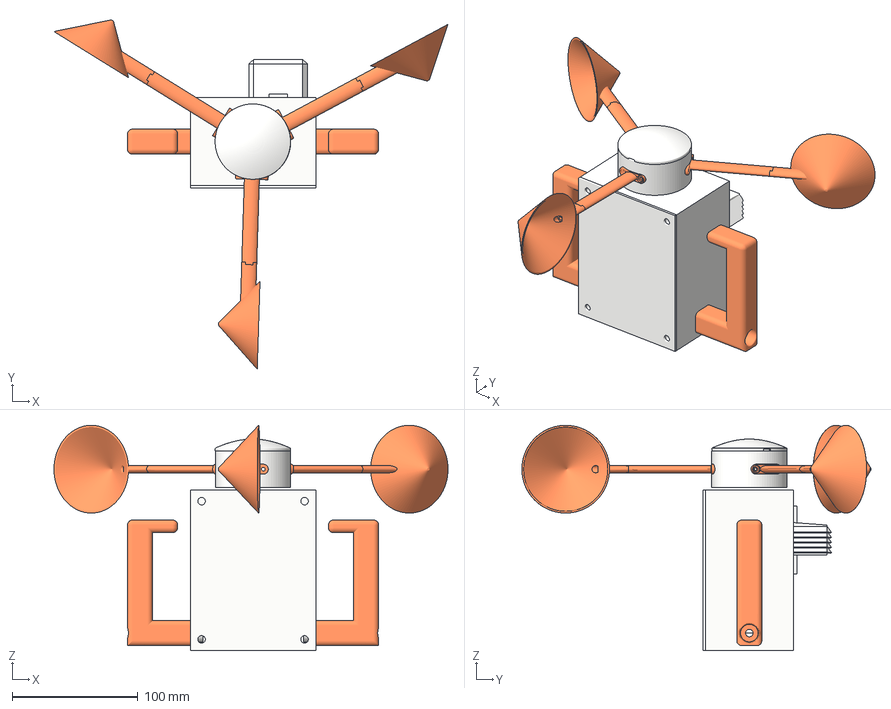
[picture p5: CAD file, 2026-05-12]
cad/printable_parts/portable_weather_station_cad_complete.3mf
313.7 x 278.1 x 179.4 mm
Accumulators
ESP32

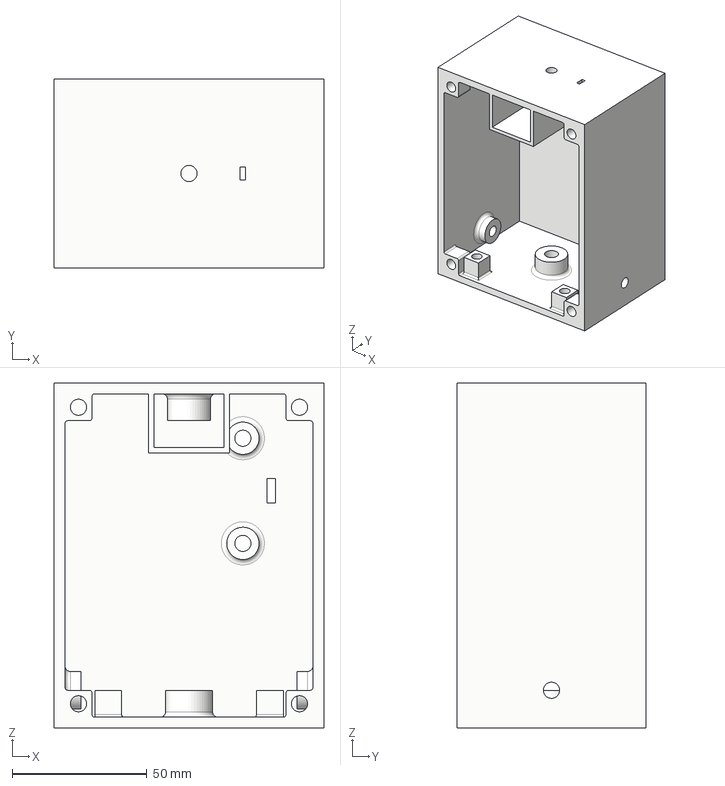
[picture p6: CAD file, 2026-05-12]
cad/printable_parts/Main body.step
100.0 x 70.0 x 128.0 mm

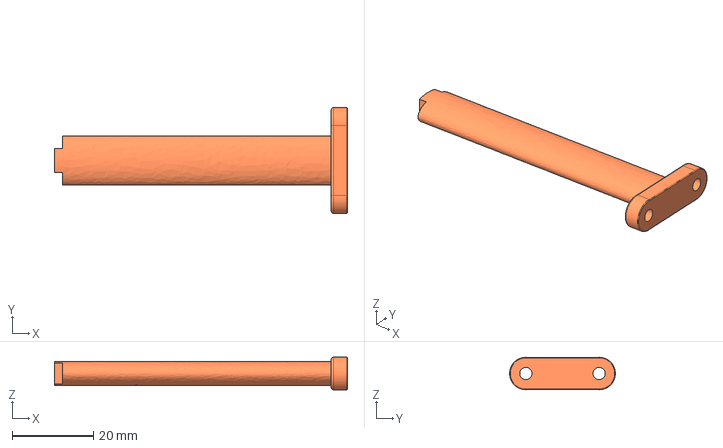
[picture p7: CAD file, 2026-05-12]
cad/printable_parts/Arm.step
72.0 x 26.0 x 8.00 mm

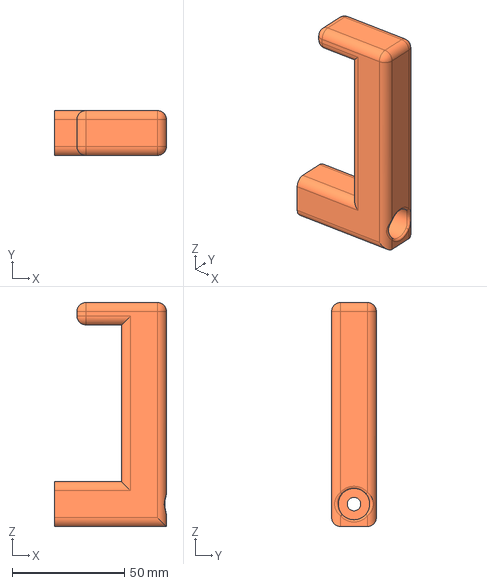
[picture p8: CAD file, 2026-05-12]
cad/printable_parts/Side handle.step
50.0 x 20.0 x 100.0 mm

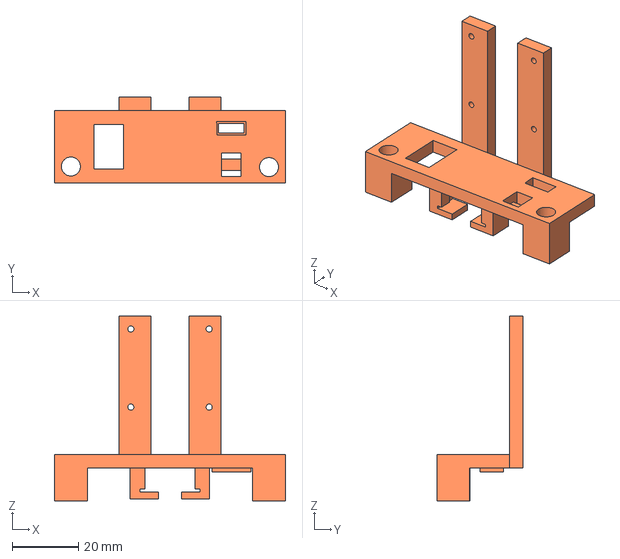
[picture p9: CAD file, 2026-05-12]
cad/printable_parts/Screen and buttons bracket.step
70.0 x 26.0 x 56.0 mm

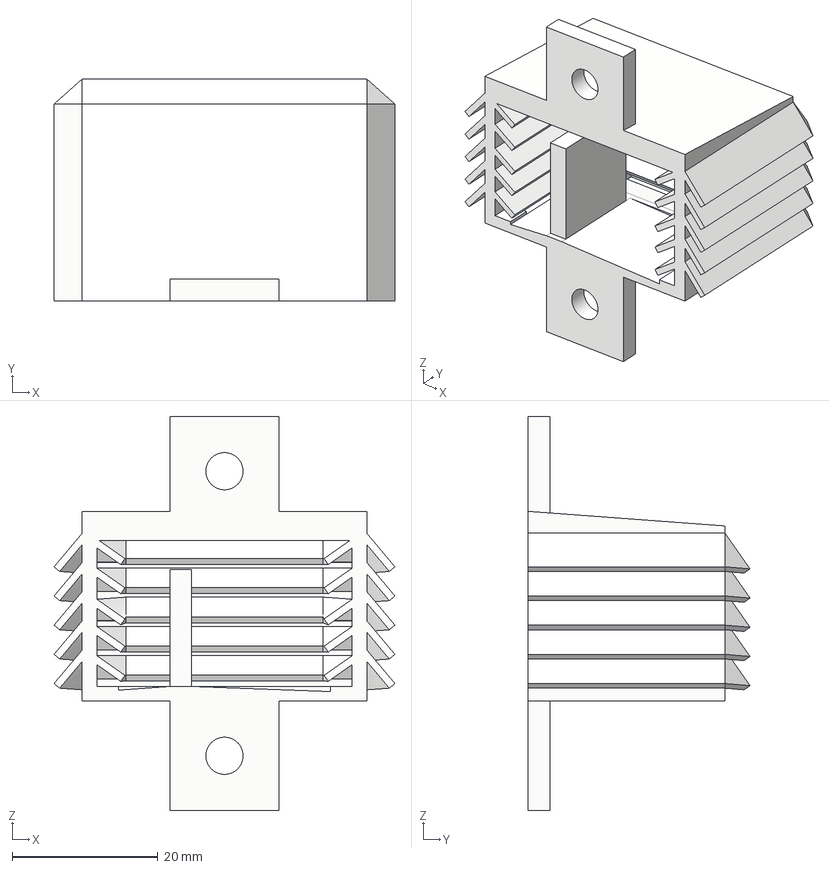
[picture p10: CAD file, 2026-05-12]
cad/printable_parts/Temperature sensor pod.step
46.7 x 30.4 x 54.0 mm

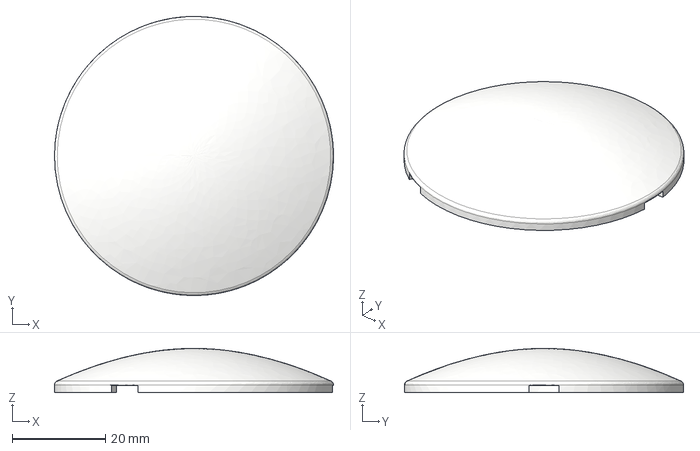
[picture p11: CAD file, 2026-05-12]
cad/printable_parts/Rotor cap.step
60.0 x 60.0 x 9.50 mm

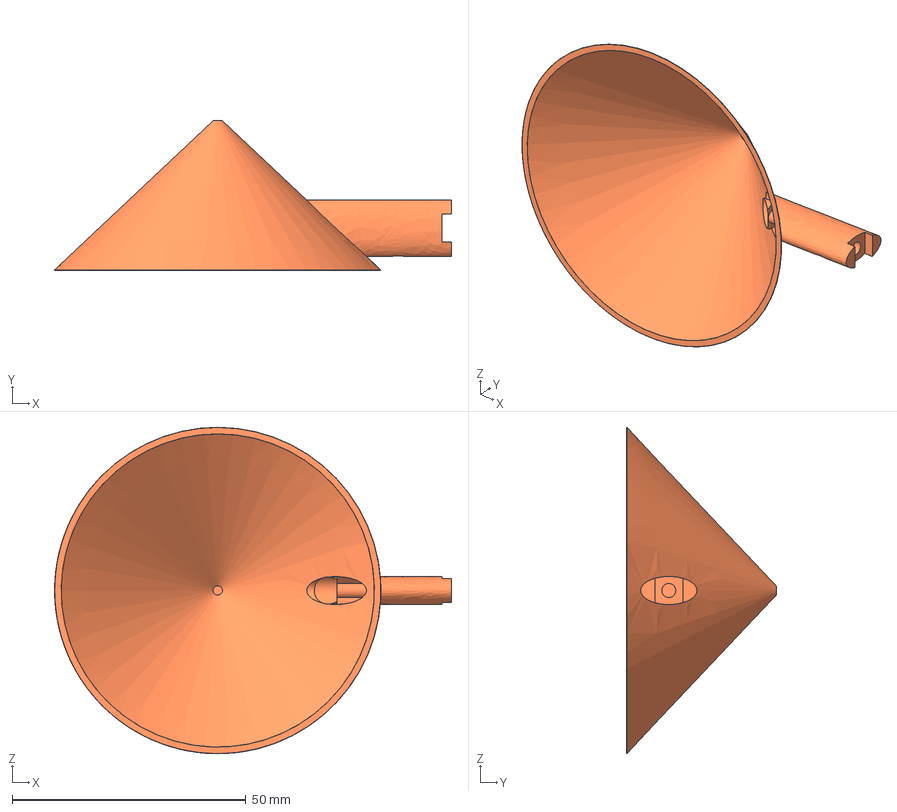
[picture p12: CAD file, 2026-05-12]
cad/printable_parts/Cup.step
84.9 x 32.0 x 69.8 mm

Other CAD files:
cad/printable_parts/Rotor base.step
cad/portable_weather_station_cad_complete.f3d
cad/printable_parts/portable_weather_station_cad_complete.stl

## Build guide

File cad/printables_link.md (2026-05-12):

https://www.printables.com/model/1719175/

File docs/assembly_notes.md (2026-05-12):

# Assembly Notes

These notes describe the assembly and first-test procedure for the current ESP32-based portable weather monitoring prototype. They are based on the uploaded firmware files:

- `portable_station_esp32.ino` — portable measurement unit / transmitter;
- `central_station_esp32.ino` — central receiving station / ThingSpeak uploader.

The current firmware configuration uses an **AHT20 sensor for temperature and relative humidity** and a **BMP280 sensor for atmospheric pressure**. It does not use a DHT22 in the uploaded code.

---

## 1. System Overview

The system consists of two main nodes:

1. **Portable measurement unit**
   - ESP32 development board;
   - AHT20 temperature and relative humidity sensor;
   - BMP280 pressure sensor;
   - OLED display;
   - custom Hall-effect cup anemometer;
   - nRF24L01 radio module;
   - 18650-based battery supply and DC-DC converters;
   - PETG enclosure and printed anemometer parts.

2. **Central receiving station**
   - ESP32 development board;
   - nRF24L01 radio module;
   - Wi-Fi connection;
   - ThingSpeak channel for online visualisation.

The general data chain is:

```text
AHT20 + BMP280 + Hall-effect anemometer
        -> portable ESP32
        -> nRF24L01 wireless link
        -> central ESP32
        -> Wi-Fi
        -> ThingSpeak
        -> remote user
```

---

## 2. Required Arduino Libraries

Install the following libraries before compiling the firmware:

### Portable measurement unit

- `Wire`
- `SPI`
- `RF24`
- `Adafruit BMP280`
- `Adafruit GFX`
- `Adafruit SSD1306`

### Central receiving station

- `SPI`
- `RF24`
- `WiFi`
- `ThingSpeak`

Use an ESP32 board package compatible with the selected ESP32 development boards.

---

## 3. Portable Measurement Unit Pinout

The uploaded transmitter firmware uses the following pin configuration.

| Function | ESP32 pin | Notes |
|---|---:|---|
| I2C SDA | GPIO 16 | Used by OLED, AHT20 and BMP280 |
| I2C SCL | GPIO 17 | Used by OLED, AHT20 and BMP280 |
| Hall sensor output | GPIO 4 | KY-003 pulse input, interrupt on falling edge |
| nRF24L01 CE | GPIO 22 | Radio control pin |
| nRF24L01 CSN | GPIO 5 | SPI chip select |
| nRF24L01 SCK | GPIO 18 | SPI clock |
| nRF24L01 MISO | GPIO 19 | SPI MISO |
| nRF24L01 MOSI | GPIO 23 | SPI MOSI |
| OLED address | `0x3C` | Change to `0x3D` in code if required |
| BMP280 address | `0x77` | Change to `0x76` in code if required |
| AHT20 address | `0x38` | Temperature and relative humidity |

Important: the code uses **GPIO 16 and GPIO 17 for I2C**, not the common ESP32 default pins GPIO 21 and GPIO 22. This is important because GPIO 22 is already used as the nRF24L01 CE pin.

---

## 4. Central Station Pinout

The uploaded receiver firmware uses the same nRF24L01 SPI pin configuration.

| Function | ESP32 pin | Notes |
|---|---:|---|
| nRF24L01 CE | GPIO 22 | Radio control pin |
| nRF24L01 CSN | GPIO 5 | SPI chip select |
| nRF24L01 SCK | GPIO 18 | SPI clock |
| nRF24L01 MISO | GPIO 19 | SPI MISO |
| nRF24L01 MOSI | GPIO 23 | SPI MOSI |

The central station firmware does not use an OLED display in the uploaded code. It receives packets from the portable station, prints information to the Serial Monitor, and uploads the received values to ThingSpeak through Wi-Fi.

---

## 5. nRF24L01 Wireless Link

Both ESP32 boards must use the same radio configuration:

| Setting | Value in firmware |
|---|---|
| Pipe address | `RxAAA` |
| Data rate | `RF24_250KBPS` |
| Payload size | 32 bytes |
| Packet magic | `0x574E4431UL` |
| Packet version | `1` |

The transmitter and receiver use the same packed `SensorPacket` structure. The packet is exactly **32 bytes**, which is the maximum payload size of the nRF24L01. If fields are added later, the packet size must be checked again on both the transmitter and receiver.

The current packet contains:

```text
magic
version
reserved
sequence number
temperature C
humidity %
sea-level pressure hPa
current/live wind speed m/s
15 s mean wind speed m/s
3 s peak/gust wind speed m/s
```

Recommended radio assembly notes:

- Power each nRF24L01 module from a stable **3.3 V** supply.
- Do not power the nRF24L01 from 5 V.
- Place a capacitor of approximately **10 uF to 100 uF** across VCC and GND close to each nRF24L01 module.
- Keep radio wiring short where possible.
- Make sure both ESP32 boards and all modules share a common ground.

---

## 6. Environmental Sensor Assembly

Connect the AHT20, BMP280 and OLED display to the same I2C bus:

```text
ESP32 GPIO 16 -> SDA
ESP32 GPIO 17 -> SCL
3.3 V         -> sensor/display VCC, if the modules support 3.3 V operation
GND           -> sensor/display GND
```

The firmware expects:

```text
AHT20 address:  0x38
BMP280 address: 0x77
OLED address:   0x3C
```

If the BMP280 is not detected, try changing this line in the transmitter firmware:

```cpp
#define BMP280_ADDRESS 0x77
```

to:

```cpp
#define BMP280_ADDRESS 0x76
```

If the OLED is not detected, try changing:

```cpp
#define OLED_ADDRESS 0x3C
```

to:

```cpp
#define OLED_ADDRESS 0x3D
```

The transmitter firmware stops during boot if the BMP280 or nRF24L01 fails to initialise. The OLED displays a short error message in these cases.

---

## 7. Anemometer Assembly

The wind-speed sensor is a custom cup anemometer using three magnets and a KY-003 Hall-effect sensor module.

### Mechanical assembly

1. Print the anemometer hub, arms and cup supports in PETG.
2. Mount the cups symmetrically to reduce imbalance and vibration.
3. Install the rotating shaft using the selected M5 screw or threaded rod.
4. Install the bearings and check that the rotor spins freely.
5. Mount three neodymium magnets on the rotating assembly.
6. Place the magnets at equal angular spacing, approximately 120 degrees apart.
7. Secure the magnets mechanically so they cannot detach during rotation.
8. Use threadlocker where appropriate to prevent loosening due to vibration.

### Hall sensor positioning

1. Fix the KY-003 Hall-effect sensor close to the path of the magnets.
2. Adjust the gap so that each magnet passage is detected reliably.
3. Make sure the rotating magnets do not touch the sensor.
4. Route the sensor wires so that they cannot interfere with the rotating assembly.
5. Test the rotor manually before powering the complete system outdoors.

The uploaded firmware uses:

```cpp
const int hallPin = 4;
const int pulsesPerRevolution = 3;
```

Therefore, the assembled anemometer must produce **three pulses per revolution**. If the number of magnets is changed, `pulsesPerRevolution` must also be changed.

---

## 8. Wind-Speed Calculation Settings

The current wind-speed conversion is a provisional functional implementation. The uploaded transmitter firmware uses:

```cpp
const float cupRadiusMeters = 0.146f;
const int pulsesPerRevolution = 3;
const float calibrationFactor = 4.2833f;
const float calibrationOffsetMps = 0.0f;
```

The basic conversion used by the firmware is:

```text
pulseHz = detected pulses per second
windSpeedMps = calibrationOffsetMps
             + pulseHz * calibrationFactor * 2 * PI * cupRadiusMeters / pulsesPerRevolution
```

The code also applies pulse rejection to reduce electrical chatter and physically unrealistic edge spacing. The current maximum valid wind gate is:

```cpp
const float MAX_VALID_WIND_KT = 70.0f;
```

The wind-speed algorithm must be calibrated against a reference anemometer before the system is used for quantitative meteorological measurements.

---

## 9. Firmware Timing

The transmitter firmware uses the following timing values:

| Function | Firmware value |
|---|---:|
| Wind sampling interval | 100 ms |
| OLED refresh interval | 500 ms |
| AHT20 + BMP280 sensor refresh interval | 1000 ms |
| Wireless transmission interval | 15000 ms |
| Live wind display window | 3000 ms |
| Gust/peak window | 3000 ms |

The receiver firmware also includes a 15000 ms ThingSpeak upload guard:

```cpp
const unsigned long THINGSPEAK_MIN_INTERVAL_MS = 15000UL;
```

In the current implementation, the transmitter sends one data packet every 15 s of accumulated wind-sampling time, and the receiver uploads accepted packets to ThingSpeak subject to the interval guard.

---

## 10. Pressure Reading and Altitude Setting

The BMP280 measures station pressure. The transmitter firmware converts this value to sea-level equivalent pressure using temperature, relative humidity and a configured altitude value.

The current code setting is:

```cpp
const float altitudeM = 0.0f;
```

Before field testing, set this value to the approximate altitude of the deployment location in metres. If it remains at `0.0f`, the sea-level reduction will effectively use sea-level altitude.

This correction is useful for display and comparison, but it should not be treated as a certified pressure measurement without comparison against a reference instrument.

---

## 11. OLED Display Information

The portable station OLED displays:

- packet sequence number;
- wind speed in knots;
- temperature in degrees Celsius;
- relative humidity in percent;
- sea-level pressure in hPa;
- Beaufort scale value, or Saffir-Simpson-equivalent category when the 15 s mean wind speed reaches the configured threshold.

The Saffir-Simpson value displayed by the prototype is only a firmware-derived equivalent based on the current wind-speed estimate. It should not be treated as an official hurricane classification, especially before anemometer calibration.

---

## 12. ThingSpeak Setup

Create a ThingSpeak channel and configure the field labels so that they match the receiver firmware.

The uploaded receiver firmware currently maps the fields as follows:

| ThingSpeak field | Firmware value |
|---|---|
| Field 1 | Temperature, degrees Celsius |
| Field 2 | Relative humidity, percent |
| Field 3 | Sea-level pressure, hPa |
| Field 4 | Current/live wind speed, m/s |
| Field 5 | 15 s mean wind speed, m/s |
| Field 6 | 3 s peak/gust wind speed, m/s |
| Field 7 | Beaufort value from 15 s mean wind speed |
| Field 8 | Saffir-Simpson-equivalent value from 15 s mean wind speed |

Important consistency check: if the ThingSpeak dashboard labels Field 1 as humidity and Field 2 as temperature, then either the ThingSpeak labels or the receiver code should be corrected. The uploaded receiver code sends temperature to Field 1 and humidity to Field 2.

Before uploading the receiver firmware, replace the placeholder values:

```cpp
const char* ssid = "YOUR_WIFI_SSID";
const char* pass = "YOUR_WIFI_PASSWORD";
unsigned long myChannelNumber = YOUR_CHANNEL_NUMBER;
const char* myWriteAPIKey = "YOUR_THINGSPEAK_WRITE_API_KEY";
```

Do not commit real Wi-Fi passwords or ThingSpeak API keys to a public GitHub repository. Use a separate `config.h` or `secrets.h` file for private credentials and add it to `.gitignore`.

---

## 13. Power Supply Assembly

The portable station is intended to be powered by two 18650 lithium-ion cells connected in series and protected by a 2S BMS module.

Recommended checks before connecting the electronics:

1. Verify the battery pack polarity.
2. Verify the 2S BMS wiring.
3. Adjust and measure each DC-DC converter output using a multimeter.
4. Confirm the 3.3 V rail before connecting the nRF24L01, AHT20, BMP280 and OLED.
5. Confirm the 5 V rail before connecting the ESP32 development board, if powering it through the 5 V/VIN input.
6. Confirm that all grounds are connected together.
7. Do not connect 5 V directly to ESP32 GPIO pins or to modules that require 3.3 V logic.

The nRF24L01 is sensitive to voltage drops. If communication is unstable, first check the 3.3 V rail, the decoupling capacitor and the common ground connection.

Lithium-ion batteries must be handled carefully. Use protected cells or a suitable BMS, avoid short circuits, and do not charge or operate damaged cells.

---

## 14. Enclosure and Weather Protection

The prototype enclosure, anemometer arms and hub are manufactured from PETG. The front panel is made from plexiglass and sealed using a silicone gasket. Cable and component ingresses are sealed using hot-melt adhesive in the current prototype.

Recommended assembly practices:

- use heat-shrink tubing on exposed solder joints;
- provide strain relief for external cables;
- avoid placing electronics directly below possible water ingress points;
- keep the pressure and humidity sensing area ventilated but protected from direct water;
- avoid direct solar heating of the temperature and humidity sensor where possible;
- consider a radiation shield for improved temperature measurements;
- use corrosion-resistant fasteners and connectors for outdoor or salt-air environments;
- replace hot-melt adhesive with more robust sealing methods for long-term outdoor deployment.

The current enclosure should be considered prototype-level protection, not a certified waterproof or storm-rated enclosure.

---

## 15. First Power-Up Procedure

Use this order for first testing.

### Step 1: Test the central station alone

1. Upload `central_station_esp32.ino` with the correct Wi-Fi and ThingSpeak settings.
2. Open the Serial Monitor at 115200 baud.
3. Confirm that the nRF24L01 initialises successfully.
4. Confirm that the ESP32 connects to Wi-Fi.
5. Wait for packets from the portable station.

Expected Serial Monitor messages include:

```text
RX v1.1 - nRF24 + ThingSpeak
Expected packet size: 32 bytes
Wi-Fi connected, IP: ...
Receiver ready
```

### Step 2: Test the portable station indoors

1. Upload `portable_station_esp32.ino`.
2. Open the Serial Monitor at 115200 baud.
3. Confirm that the OLED starts correctly.
4. Confirm that the BMP280 is detected.
5. Confirm that the nRF24L01 initialises successfully.
6. Confirm that temperature, humidity and pressure values appear on the OLED.
7. Rotate the anemometer manually and check that wind values respond.

Expected Serial Monitor messages include:

```text
TX v3.3 - stable efficient wind sampler
Packet size: 32 bytes
Wind coefficient: ...
TX interval: 15000 ms
TX ready
```

### Step 3: Test wireless communication

1. Keep both ESP32 boards powered.
2. Place the units close to each other for the first test.
3. Wait at least 15 s for the first transmitted packet.
4. Confirm that the receiver prints the packet sequence number and sensor values.
5. Confirm that ThingSpeak updates the configured fields.

### Step 4: Test the anemometer

1. Rotate the cups slowly by hand.
2. Confirm that the OLED wind value changes.
3. Confirm that the receiver receives non-zero wind values.
4. Check for unstable values caused by poor sensor alignment, magnet spacing or electrical noise.

---

## 16. Pre-Deployment Checklist

Before outdoor testing, verify the following:

- the AHT20, BMP280 and OLED are connected to GPIO 16 and GPIO 17;
- the BMP280 address matches the physical module;
- the OLED address matches the physical display;
- the Hall sensor output is connected to GPIO 4;
- the anemometer has three magnets if `pulsesPerRevolution = 3`;
- the magnet-to-sensor gap is reliable but does not cause contact;
- the nRF24L01 modules are powered from stable 3.3 V rails;
- decoupling capacitors are installed near the nRF24L01 modules;
- both nRF24L01 modules use the same pipe address and payload structure;
- the central station Wi-Fi credentials are correct;
- the ThingSpeak channel fields match the receiver firmware mapping;
- the altitude value in the transmitter firmware is set correctly for the test location;
- the battery pack and DC-DC converter outputs have been checked with a multimeter;
- all grounds are common;
- the enclosure is closed and cables have strain relief;
- the station is mounted securely and the anemometer can rotate freely.

---

## 17. Known Limitations

The current system is a functional prototype. The following limitations should be considered during assembly, testing and documentation:

- the wind-speed conversion is not yet calibrated against a reference anemometer;
- the pressure correction depends on the altitude value configured in the firmware;
- temperature and humidity readings may be affected by enclosure heating, poor ventilation and direct sunlight;
- the PETG enclosure is not an IP-rated weatherproof enclosure;
- the nRF24L01 link is intended for short-range testing and may be affected by 2.4 GHz interference;
- battery autonomy has not yet been fully characterised;
- the system depends on the central station Wi-Fi connection for online publication;
- the system is not intended for official warnings, navigation decisions, certified measurements or safety-critical decisions.

Future improvements may include calibrated wind-speed measurement, comparison with reference instruments, improved waterproofing, corrosion-resistant connectors, solar charging, local data logging, battery monitoring and longer-range communication using LoRa modules.

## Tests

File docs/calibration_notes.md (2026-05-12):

# Calibration Notes

These notes describe the calibration and adjustment procedure for the current ESP32-based portable weather monitoring prototype. They are based on the uploaded firmware files:

- `portable_station_esp32.ino` — portable measurement unit / transmitter;
- `central_station_esp32.ino` — central receiving station / ThingSpeak uploader.

The current prototype is suitable for **functional testing**, but it should not be treated as a certified meteorological instrument until its measurements are compared with appropriate reference instruments.

---

## 1. Current Calibration Status

The uploaded firmware contains a provisional wind-speed conversion algorithm. It uses the anemometer geometry, the number of magnets, and a provisional calibration factor to convert Hall-effect pulses into wind speed.

Current transmitter settings:

```cpp
const float cupRadiusMeters = 0.146f;           // shaft centre -> cup centre
const int pulsesPerRevolution = 3;              // 3 magnets
const float calibrationFactor = 4.2833f;        // geometry-derived first estimate
const float calibrationOffsetMps = 0.0f;        // keep 0 unless later calibrated
const float altitudeM = 0.0f;                   // set real altitude if needed
```

Important notes:

- the current wind-speed factor is a **first estimate**, not a certified calibration;
- the anemometer uses **three magnets**, so the firmware expects **three pulses per revolution**;
- the pressure value transmitted by the system is a **sea-level equivalent pressure**, calculated using the configured altitude value;
- the current altitude value is `0.0f`, so it should be changed before field testing if the station is not at sea level;
- temperature, humidity, pressure and wind-speed readings should all be compared with suitable reference instruments before being used as quantitative meteorological measurements.

---

## 2. Wind-Speed Measurement Principle

The wind sensor is a custom Hall-effect cup anemometer.

Mechanical and electrical principle:

1. The rotating anemometer assembly carries three neodymium magnets.
2. A KY-003 Hall-effect sensor is fixed close to the magnet path.
3. Each magnet passage generates one digital pulse.
4. The ESP32 counts accepted pulses using an interrupt on GPIO 4.
5. Pulse frequency is converted into wind speed by the firmware.

The uploaded code uses:

```cpp
const int hallPin = 4;
attachInterrupt(digitalPinToInterrupt(hallPin), onMagnetDetected, FALLING);
```

The conversion is based on the following relationship:

```text
pulseHz = accepted pulses per second
revPerSecond = pulseHz / pulsesPerRevolution
cupSpeedMps = 2 * PI * cupRadiusMeters * revPerSecond
windSpeedMps = calibrationOffsetMps + calibrationFactor * cupSpeedMps
```

Equivalent firmware expression:

```text
windSpeedMps = calibrationOffsetMps
             + pulseHz * calibrationFactor * 2 * PI * cupRadiusMeters / pulsesPerRevolution
```

With the current constants, the firmware coefficient is approximately:

```text
WIND_MPS_PER_PULSE_HZ = 1.309755 m/s per pulse/s
WIND_KT_PER_PULSE_HZ  = 2.545954 kt per pulse/s
```

This means that, in the current firmware, a measured pulse frequency of `1 pulse/s` corresponds to approximately `1.31 m/s`, before considering the limitations of the provisional calibration.

---

## 3. Wind Values Produced by the Firmware

The transmitter calculates and sends three wind-speed values:

| Packet value | Meaning | Firmware basis |
|---|---|---|
| `windInstantMps` | current/live displayed wind speed | smoothed value from recent pulse bins |
| `windMeanMps` | mean wind speed over the 15 s transmission interval | accumulated accepted pulses over the report interval |
| `windPeakMps` | peak/gust value inside the 15 s interval | highest rolling 3 s wind value during the interval |

The receiver uploads these values to ThingSpeak using the following field mapping:

| ThingSpeak field | Firmware value |
|---|---|
| Field 1 | Temperature, degrees Celsius |
| Field 2 | Relative humidity, percent |
| Field 3 | Sea-level pressure, hPa |
| Field 4 | Current/live wind speed, m/s |
| Field 5 | 15 s mean wind speed, m/s |
| Field 6 | 3 s peak/gust wind speed, m/s |
| Field 7 | Beaufort value from 15 s mean wind speed |
| Field 8 | Saffir-Simpson-equivalent value from 15 s mean wind speed |

For calibration, the most useful value is usually **Field 5: 15 s mean wind speed**, because it is less noisy than the live value and better represents the full transmission interval.

---

## 4. Pulse Filtering and Edge Rejection

The transmitter uses a simple electrical debounce filter for the Hall-effect sensor interrupt. The previous wind-speed-based edge gate, which rejected edges above an estimated `70 kt` threshold, has been removed.

Relevant settings:

```cpp
const unsigned long ELECTRICAL_DEBOUNCE_US = 5000UL;
const unsigned long EDGE_GATE_US = ELECTRICAL_DEBOUNCE_US;
```

Any Hall edge arriving sooner than `5000 us` after the previous accepted edge is rejected as probable electrical chatter. This is a debounce filter only; it is not intended to impose a wind-speed limit or reject pulses based on a Saffir-Simpson or Beaufort threshold.

Important notes:

- removing the `70 kt` edge gate avoids artificially limiting high wind-speed pulse detection;
- the remaining `5000 us` debounce still rejects extremely fast repeated edges caused by noise or unstable triggering;
- with the current provisional wind coefficient, a `5000 us` interval corresponds to a much higher theoretical wind speed than the intended prototype test range, so it should not affect normal functional testing;
- if false pulses appear, improve wiring, grounding, sensor mounting and magnet alignment before increasing the debounce value.

During testing, the transmitter Serial Monitor prints useful diagnostic information, including:

```text
pulses=...
rejected=...
gateUs=...
shortestAcceptedUs=...
```

A high number of rejected edges may indicate electrical noise, poor magnet/sensor alignment, excessive vibration, or an unsuitable debounce setting.

---

## 5. Preliminary Checks Before Calibration

Before comparing the anemometer with a reference instrument, complete these checks.

### 5.1 Mechanical checks

- Confirm that the anemometer rotates freely.
- Confirm that the cups are mounted symmetrically.
- Confirm that the shaft is straight and the bearings are not binding.
- Confirm that the magnets are firmly fixed and equally spaced.
- Confirm that the KY-003 sensor does not touch the rotating assembly.
- Confirm that the sensor gap is small enough for reliable detection but large enough to avoid contact.

### 5.2 Pulse-counting checks

The firmware expects:

```cpp
const int pulsesPerRevolution = 3;
```

Therefore, one complete revolution of the rotor should produce three accepted pulses.

Manual rotation is useful for checking pulse detection, but it is **not** a valid wind-speed calibration method because it does not reproduce real aerodynamic behaviour.

### 5.3 Zero-wind check

With the anemometer stationary:

- the displayed wind speed should settle close to `0.0 m/s`;
- the accepted pulse count should not increase continuously;
- the rejected edge count should not increase rapidly;
- if non-zero wind is shown while the rotor is stationary, check wiring, grounding, pull-up behaviour, sensor placement and electrical noise.

---

## 6. Recommended Wind Calibration Procedure

A proper wind calibration requires comparison against a reference anemometer. The reference instrument should be placed as close as practical to the prototype anemometer while avoiding wake effects and physical interference.

### 6.1 Required equipment

Recommended equipment:

- reference anemometer;
- stable airflow source, such as a controlled fan setup or wind tunnel;
- laptop connected to the ESP32 Serial Monitor;
- access to the ThingSpeak channel, if online logging is used;
- notebook or CSV file for recording calibration data.

A wind tunnel or controlled airflow setup is preferred. Outdoor calibration is possible, but it is more difficult because wind speed changes rapidly and the reference and prototype may not experience identical airflow.

### 6.2 Test setup

1. Mount the prototype anemometer securely.
2. Mount the reference anemometer close to it, at a similar height and orientation.
3. Avoid placing one instrument directly behind the other.
4. Keep the anemometer away from walls, corners, table edges or other objects that distort airflow.
5. Start the transmitter and receiver.
6. Confirm that the transmitter sends packets every 15 s.
7. Confirm that the receiver displays and/or uploads the wind values.

### 6.3 Data collection

For each airflow level:

1. Allow the airflow and rotor speed to stabilise.
2. Record the reference wind speed over the same interval as the prototype report.
3. Record the prototype `windMeanMps` value.
4. Record the number of accepted pulses and elapsed time if using Serial Monitor data.
5. Repeat each test point at least three times.
6. Use several wind-speed levels, including low, medium and higher values within the safe range of the test setup.

Suggested CSV structure:

```text
timestamp,test_point,reference_wind_mps,prototype_mean_mps,prototype_current_mps,prototype_peak_mps,report_pulses,report_elapsed_ms,computed_pulse_hz,rejected_edges,notes
```

The pulse frequency can be calculated from Serial Monitor data as:

```text
computed_pulse_hz = report_pulses / (report_elapsed_ms / 1000)
```

For best results, use the 15 s mean wind value rather than the live display value.

---

## 7. Calculating New Wind Calibration Constants

There are two practical ways to update the wind calibration constants.

### Method A: Calibration from raw pulse frequency

This is the cleanest method if `report_pulses` and `report_elapsed_ms` are recorded.

The base coefficient without the calibration factor is:

```text
baseCoefficient = 2 * PI * cupRadiusMeters / pulsesPerRevolution
```

With the current geometry:

```text
baseCoefficient = 0.305782 m/s per pulse/s
```

Fit a linear relationship between the reference wind speed and the measured pulse frequency:

```text
referenceWindMps = offset + slopePulse * pulseHz
```

Then update the firmware constants as:

```text
calibrationFactor = slopePulse / baseCoefficient
calibrationOffsetMps = offset
```

If the fitted offset is very small and not physically meaningful, it may be preferable to keep:

```cpp
const float calibrationOffsetMps = 0.0f;
```

and use a zero-intercept fit.

### Method B: Calibration from the current firmware wind output

This method is easier if only the current firmware output is available.

Fit a linear relationship between the reference wind speed and the current reported 15 s mean wind speed:

```text
referenceWindMps = offset + slopeReported * prototypeMeanMps
```

Because the current firmware offset is `0.0f`, the updated constants can be estimated as:

```text
newCalibrationFactor = oldCalibrationFactor * slopeReported
newCalibrationOffsetMps = offset
```

For the uploaded firmware:

```text
oldCalibrationFactor = 4.2833
```

Example:

```text
If slopeReported = 0.85,
newCalibrationFactor = 4.2833 * 0.85 = 3.6408
```

After updating the constants, upload the firmware again and repeat the comparison with the reference anemometer.

---

## 8. Error Metrics After Calibration

After applying the new constants, collect a new verification dataset and calculate basic error indicators.

For each test point:

```text
error = prototypeWindMps - referenceWindMps
absoluteError = abs(error)
percentageError = 100 * error / referenceWindMps
```

For the whole dataset:

```text
meanError = average(error)
meanAbsoluteError = average(abs(error))
RMSE = sqrt(average(error^2))
```

Do not calculate percentage error for very low wind speeds close to zero, because the result may become misleading.

A simple calibration summary should include:

- number of test points;
- wind-speed range tested;
- reference instrument used;
- old calibration constants;
- new calibration constants;
- mean error;
- mean absolute error;
- RMSE;
- notes about test conditions.

---

## 9. Pressure Calibration and Altitude Setting

The BMP280 measures pressure at the station. The transmitter firmware then converts this to sea-level equivalent pressure using the configured altitude, temperature and relative humidity.

Current altitude setting:

```cpp
const float altitudeM = 0.0f;
```

Before field testing, set `altitudeM` to the approximate altitude of the deployment location in metres.

Important distinction:

- **station pressure** is the actual pressure measured at the sensor location;
- **sea-level pressure** is a corrected value intended for easier comparison between locations at different altitudes.

The current firmware transmits `seaLevelHpa`, not raw station pressure.

Recommended pressure checks:

1. Set the correct altitude value in the transmitter firmware.
2. Place the station near a trusted reference barometer or weather station.
3. Allow the sensor to stabilise.
4. Compare the reported sea-level pressure with the reference sea-level pressure.
5. If comparing against station pressure instead, modify the firmware to print or transmit the raw BMP280 pressure value.

The pressure correction depends on:

- the accuracy of the configured altitude;
- the BMP280 sensor reading;
- the local temperature and humidity values used by the correction function;
- the representativeness of the reference pressure value.

If a systematic pressure offset is observed after setting the correct altitude, a future firmware version may include a pressure offset constant, for example:

```cpp
const float pressureOffsetHpa = 0.0f;
```

The current uploaded firmware does not include this offset.

---

## 10. Temperature and Relative Humidity Checks

The uploaded transmitter firmware uses an AHT20 sensor for temperature and relative humidity.

Current AHT20 address:

```cpp
#define AHT20_ADDRESS 0x38
```

Recommended checks:

1. Place the prototype near a reference temperature and humidity instrument.
2. Keep both instruments away from direct sunlight, hands, hot electronics and airflow from fans unless that airflow is part of the test.
3. Allow enough time for the sensors to stabilise.
4. Compare readings at several conditions if possible.
5. Record the difference between the prototype and the reference instrument.

Possible sources of error:

- heat from the ESP32 and DC-DC converters;
- direct solar radiation;
- poor ventilation inside the enclosure;
- water ingress or condensation;
- sensor placement too close to the enclosure wall or internal electronics;
- lack of a radiation shield during outdoor use.

If a systematic offset is observed, future firmware versions may include correction constants, for example:

```cpp
const float temperatureOffsetC = 0.0f;
const float humidityOffsetPct = 0.0f;
```

The current uploaded firmware does not include these offsets.

---

## 11. Beaufort and Saffir-Simpson-Equivalent Display

Both firmware files contain helper functions for Beaufort and Saffir-Simpson-equivalent values.

Important limitations:

- these values are calculated from the prototype wind-speed estimate;
- the wind-speed estimate is not yet calibrated;
- the receiver calculates the Saffir-Simpson-equivalent value from the 15 s mean wind speed;
- this is not an official hurricane classification;
- the Saffir-Simpson-equivalent value should be treated only as an indicative firmware display feature.

Until the anemometer is calibrated and tested, the system should not be used to classify hurricane intensity or support safety-critical decisions.

---

## 12. Recommended Calibration Record

Keep a calibration record in the repository, for example in a file named:

```text
docs/calibration_record.md
```

Suggested content:

```text
Calibration date:
Location:
Operator:
Prototype version:
Firmware version:
Reference anemometer:
Reference pressure instrument:
Reference temperature/humidity instrument:
Anemometer radius used in firmware:
Pulses per revolution:
Old calibration factor:
Old calibration offset:
New calibration factor:
New calibration offset:
Altitude setting:
Wind-speed range tested:
Number of calibration points:
Mean error:
Mean absolute error:
RMSE:
Notes:
```

Also keep the raw calibration data where possible, for example:

```text
data/wind_calibration_YYYY-MM-DD.csv
```

Do not delete old calibration records. They are useful for tracking design changes, firmware changes and mechanical modifications.

---

## 13. When Recalibration Is Required

Recalibrate or at least re-check the wind-speed measurement if any of the following changes are made:

- the cup radius changes;
- the number of magnets changes;
- the magnet positions change;
- the cup shape changes;
- the bearing type or shaft friction changes significantly;
- the Hall sensor position changes;
- the pulse filtering settings change;
- the anemometer is repaired after damage;
- the firmware wind-speed calculation is modified.

Re-check pressure, temperature and humidity measurements if:

- the sensor module is replaced;
- the sensor position inside the enclosure changes;
- ventilation or radiation shielding is changed;
- the altitude setting is changed;
- the enclosure is modified in a way that affects heating or airflow.

---

## 14. Current Prototype Limitations

The current prototype should be documented with the following limitations:

- wind-speed conversion is provisional and requires calibration against a reference anemometer;
- pressure output depends on the altitude value configured in firmware;
- temperature and humidity may be affected by enclosure heating and ventilation;
- the PETG enclosure is not a certified weatherproof or storm-rated enclosure;
- the nRF24L01 link is intended for short-range functional testing;
- ThingSpeak values depend on the Wi-Fi connection and the central station upload process;
- the system is not intended for official meteorological reporting, navigation decisions, emergency warnings or safety-critical decisions.

The project should be described as a **functional prototype** and a **complementary local observation tool**, not as a replacement for certified meteorological stations.

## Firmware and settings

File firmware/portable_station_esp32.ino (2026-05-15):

#include <Wire.h>
#include <Adafruit_BMP280.h>
#include <Adafruit_GFX.h>
#include <Adafruit_SSD1306.h>

#include <SPI.h>
#include <nRF24L01.h>
#include <RF24.h>

#include <math.h>

// =====================================================
// USER SETTINGS
// =====================================================
const unsigned long WIND_BIN_MS       = 100UL;    // pulse-count bin interval
const unsigned long TX_INTERVAL_MS    = 1000UL;   // RF packet interval
const unsigned long OLED_UPDATE_MS    = 500UL;    // OLED refresh
const unsigned long SENSOR_UPDATE_MS  = 1000UL;   // AHT20 + BMP280 refresh

// =====================================================
// ANEMOMETER GEOMETRY
// =====================================================
// Magnet radius is informational only.
// It is NOT used in wind-speed conversion.
const float magnetRadiusMeters = 0.020f;          // 20 mm

// Important wind-conversion radius:
// shaft center -> cup center.
const float cupRadiusMeters = 0.146f;             // 146 mm

const float cupAssemblyDiameterMeters = cupRadiusMeters * 2.0f;

// Three magnets at 120 degrees.
// Must equal accepted Hall pulses per real rotor revolution.
const int pulsesPerRevolution = 3;

// Starting calibration estimate.
// This is not pure geometry. Adjust after comparing to a reference anemometer.
const float calibrationFactor = 2.7f;
const float calibrationOffsetMps = 0.0f;

// Set this to real station altitude above mean sea level.
const float altitudeM = 0.0f;

// =====================================================
// WIND MEASUREMENT SETTINGS
// =====================================================
const float TWO_PI_F = 6.28318530718f;

const float CUP_CIRCUMFERENCE_M =
  TWO_PI_F * cupRadiusMeters;

const float WIND_MPS_PER_RPS =
  calibrationFactor * CUP_CIRCUMFERENCE_M;

const float WIND_MPS_PER_RPM =
  WIND_MPS_PER_RPS / 60.0f;

const float WIND_MPS_PER_PULSE_HZ =
  WIND_MPS_PER_RPS / (float)pulsesPerRevolution;

// Rolling RPM/RPS window.
// Shorter = faster but noisier.
// Longer = smoother but slower.
const unsigned long WIND_WINDOW_MS = 3000UL;
const unsigned long WIND_MIN_WINDOW_MS = 1500UL;

// 50 bins x 100 ms = around 5 seconds of history.
const uint8_t WIND_RING_SIZE = 50;

// Small electrical debounce only.
// If pulse count is too high, try 2000 or 3000.
// If pulse count is too low at high RPM, try 0.
const unsigned long HALL_DEBOUNCE_US = 1000UL;

// Local 15 s OLED mean preview.
const unsigned long WIND_MEAN_WINDOW_MS = 15000UL;
const unsigned long WIND_MEAN_MIN_MS    = 3000UL;
const uint8_t WIND_MEAN_RING_SIZE = 20;

// =====================================================
// AHT20 / BMP280
// =====================================================
#define AHT20_ADDRESS 0x38
#define BMP280_ADDRESS 0x77   // change to 0x76 if needed

Adafruit_BMP280 bmp;
bool bmpOk = false;

// =====================================================
// OLED
// =====================================================
#define SCREEN_WIDTH 128
#define SCREEN_HEIGHT 64
#define OLED_RESET -1
#define OLED_ADDRESS 0x3C     // change to 0x3D if needed

Adafruit_SSD1306 display(SCREEN_WIDTH, SCREEN_HEIGHT, &Wire, OLED_RESET);
bool oledOk = false;

// =====================================================
// nRF24
// =====================================================
// Use the CE/CSN pins that worked in your radio-only test.
#define CE_PIN    22
#define CSN_PIN    5
#define SCK_PIN   18
#define MISO_PIN  19
#define MOSI_PIN  23

const uint8_t RADIO_CHANNEL = 76;

RF24 radio(CE_PIN, CSN_PIN);
const byte pipeAddress[6] = "RxAAA";

// =====================================================
// KY-003 Hall sensor
// =====================================================
const int hallPin = 4;

volatile uint32_t hallPulseTotal = 0;
volatile uint32_t hallRejectedBounce = 0;
volatile unsigned long lastHallPulseUs = 0;

// =====================================================
// COMPACT RF PACKET
// Fixed 14-byte payload.
// Must match receiver exactly.
// =====================================================
struct __attribute__((packed)) WeatherPacket {
  uint32_t txMs;             // transmitter millis()
  uint16_t sampleMs;         // RF sample duration
  uint16_t windMpsX10;       // wind m/s * 10
  int16_t  temperatureCx10;  // temperature C * 10
  uint16_t humidityX10;      // RH % * 10
  uint16_t seaLevelHpaX10;   // sea-level pressure hPa * 10
};

// =====================================================
// GLOBAL STATE
// =====================================================
unsigned long lastWindBinMs = 0;
unsigned long lastTxMs = 0;
unsigned long lastOledUpdateMs = 0;
unsigned long lastSensorUpdateMs = 0;
unsigned long lastTxWindSampleMs = 0;

uint32_t lastWindBinPulseTotal = 0;

float temperatureC = 20.0f;
float humidityPct = 50.0f;
float stationPressureHpa = 1013.25f;
float seaLevelHpa = 1013.25f;

// Single wind value used by OLED and RF.
float latestWindMps = 0.0f;
float latestMean15Mps = 0.0f;

// Debug values
float latestRotorRps = 0.0f;
float latestRotorRpm = 0.0f;
uint32_t latestWindowPulses = 0;
unsigned long latestWindowMs = 0;

// =====================================================
// WIND RING BUFFER
// =====================================================
struct WindBin {
  uint16_t elapsedMs;
  uint16_t pulses;
};

WindBin windRing[WIND_RING_SIZE];
uint8_t windWriteIndex = 0;
uint8_t windValidCount = 0;

// =====================================================
// LOCAL 15 s MEAN HISTORY
// =====================================================
struct WindSample {
  uint16_t sampleMs;
  uint16_t windMpsX10;
};

WindSample windMeanRing[WIND_MEAN_RING_SIZE];
uint8_t windMeanWriteIndex = 0;
uint8_t windMeanCount = 0;

// =====================================================
// CONVERSIONS / SCALES
// =====================================================
float mpsToKt(float mps) {
  return mps * 1.94384f;
}

float mpsToKmh(float mps) {
  return mps * 3.6f;
}

float windMpsFromRotorRps(float rotorRps) {
  float windMps = WIND_MPS_PER_RPS * rotorRps + calibrationOffsetMps;

  if (windMps < 0.0f) {
    windMps = 0.0f;
  }

  return windMps;
}

float windMpsFromRotorRpm(float rotorRpm) {
  return windMpsFromRotorRps(rotorRpm / 60.0f);
}

uint16_t packMpsX10(float value) {
  if (value < 0.0f) {
    value = 0.0f;
  }

  float packed = value * 10.0f;

  if (packed > 65535.0f) {
    packed = 65535.0f;
  }

  return (uint16_t)lroundf(packed);
}

float unpackMpsX10(uint16_t value) {
  return value / 10.0f;
}

int16_t packTempCx10(float value) {
  return (int16_t)lroundf(value * 10.0f);
}

uint16_t packUnsignedX10(float value) {
  if (value < 0.0f) {
    value = 0.0f;
  }

  float packed = value * 10.0f;

  if (packed > 65535.0f) {
    packed = 65535.0f;
  }

  return (uint16_t)lroundf(packed);
}

uint8_t beaufortFromMps(float mps) {
  if (mps < 0.5f)  return 0;
  if (mps < 1.6f)  return 1;
  if (mps < 3.4f)  return 2;
  if (mps < 5.5f)  return 3;
  if (mps < 8.0f)  return 4;
  if (mps < 10.8f) return 5;
  if (mps < 13.9f) return 6;
  if (mps < 17.2f) return 7;
  if (mps < 20.8f) return 8;
  if (mps < 24.5f) return 9;
  if (mps < 28.5f) return 10;
  if (mps < 32.7f) return 11;
  return 12;
}

uint8_t sshwsEquivalentFromMps(float mps) {
  if (mps < 32.925f) return 0;
  if (mps < 42.700f) return 1;
  if (mps < 49.400f) return 2;
  if (mps < 58.100f) return 3;
  if (mps < 70.000f) return 4;
  return 5;
}

// =====================================================
// HALL ISR
// =====================================================
void IRAM_ATTR onHallPulse() {
  unsigned long nowUs = micros();

  if (HALL_DEBOUNCE_US > 0 && lastHallPulseUs != 0) {
    unsigned long dtUs = nowUs - lastHallPulseUs;

    if (dtUs < HALL_DEBOUNCE_US) {
      hallRejectedBounce++;
      return;
    }
  }

  lastHallPulseUs = nowUs;
  hallPulseTotal++;
}

// =====================================================
// HALL HELPERS
// =====================================================
uint32_t getHallPulseTotal() {
  noInterrupts();
  uint32_t value = hallPulseTotal;
  interrupts();

  return value;
}

void snapshotHallCounters(uint32_t &pulsesOut, uint32_t &rejectedOut) {
  noInterrupts();
  pulsesOut = hallPulseTotal;
  rejectedOut = hallRejectedBounce;
  interrupts();
}

// =====================================================
// WIND RING HELPERS
// =====================================================
void clearWindRing() {
  windWriteIndex = 0;
  windValidCount = 0;

  for (uint8_t i = 0; i < WIND_RING_SIZE; i++) {
    windRing[i].elapsedMs = 0;
    windRing[i].pulses = 0;
  }
}

void addWindBin(uint16_t elapsedMs, uint16_t pulses) {
  windRing[windWriteIndex].elapsedMs = elapsedMs;
  windRing[windWriteIndex].pulses = pulses;

  windWriteIndex++;

  if (windWriteIndex >= WIND_RING_SIZE) {
    windWriteIndex = 0;
  }

  if (windValidCount < WIND_RING_SIZE) {
    windValidCount++;
  }
}

bool rotorRpsFromRing(float &rpsOut) {
  unsigned long totalMs = 0;
  uint32_t totalPulses = 0;

  for (uint8_t n = 0; n < windValidCount; n++) {
    int index = (int)windWriteIndex - 1 - n;

    while (index < 0) {
      index += WIND_RING_SIZE;
    }

    uint16_t binMs = windRing[index].elapsedMs;

    if (binMs == 0) {
      continue;
    }

    // Use complete bins only.
    // This avoids counting all pulses from a bin while using only part of its time.
    if (totalMs >= WIND_WINDOW_MS) {
      break;
    }

    totalMs += binMs;
    totalPulses += windRing[index].pulses;
  }

  latestWindowMs = totalMs;
  latestWindowPulses = totalPulses;

  if (totalMs < WIND_MIN_WINDOW_MS || totalMs == 0) {
    rpsOut = 0.0f;
    return false;
  }

  float seconds = (float)totalMs / 1000.0f;
  float rotations = (float)totalPulses / (float)pulsesPerRevolution;

  rpsOut = rotations / seconds;
  return true;
}

// =====================================================
// 15 s MEAN HELPERS
// =====================================================
void clearWindMeanRing() {
  windMeanWriteIndex = 0;
  windMeanCount = 0;

  for (uint8_t i = 0; i < WIND_MEAN_RING_SIZE; i++) {
    windMeanRing[i].sampleMs = 0;
    windMeanRing[i].windMpsX10 = 0;
  }
}

void addWindMeanSample(uint16_t sampleMs, uint16_t windMpsX10) {
  windMeanRing[windMeanWriteIndex].sampleMs = sampleMs;
  windMeanRing[windMeanWriteIndex].windMpsX10 = windMpsX10;

  windMeanWriteIndex++;

  if (windMeanWriteIndex >= WIND_MEAN_RING_SIZE) {
    windMeanWriteIndex = 0;
  }

  if (windMeanCount < WIND_MEAN_RING_SIZE) {
    windMeanCount++;
  }
}

bool meanMpsFromRecentSamples(
  unsigned long targetWindowMs,
  unsigned long minimumWindowMs,
  float &meanMpsOut
) {
  unsigned long totalMs = 0;
  float weightedSum = 0.0f;

  for (uint8_t n = 0; n < windMeanCount && totalMs < targetWindowMs; n++) {
    int index = (int)windMeanWriteIndex - 1 - n;

    while (index < 0) {
      index += WIND_MEAN_RING_SIZE;
    }

    uint16_t sampleMs = windMeanRing[index].sampleMs;

    if (sampleMs == 0) {
      continue;
    }

    unsigned long remainingMs = targetWindowMs - totalMs;
    unsigned long usedMs = sampleMs;

    if (usedMs > remainingMs) {
      usedMs = remainingMs;
    }

    float mps = unpackMpsX10(windMeanRing[index].windMpsX10);

    weightedSum += mps * (float)usedMs;
    totalMs += usedMs;
  }

  if (totalMs < minimumWindowMs || totalMs == 0) {
    meanMpsOut = 0.0f;
    return false;
  }

  meanMpsOut = weightedSum / (float)totalMs;
  return true;
}

// =====================================================
// SEA LEVEL REDUCTION
// =====================================================
float reduceToSeaLevelWMO(
  float stationPressureHpa,
  float tempC,
  float rhPercent,
  float altitudeMeters
) {
  const float Kp = 0.0148275f;
  const float a  = 0.0065f;
  const float Ch = 0.12f;

  float Ts = 273.15f + tempC;
  float esat = 6.112f * exp((17.67f * tempC) / (tempC + 243.5f));
  float es = (rhPercent / 100.0f) * esat;
  float Tmv = Ts + (a * altitudeMeters / 2.0f) + (es * Ch);
  float exponent = (Kp * altitudeMeters) / Tmv;

  return stationPressureHpa * pow(10.0f, exponent);
}

// =====================================================
// AHT20
// =====================================================
void initAHT20() {
  Wire.beginTransmission(AHT20_ADDRESS);
  Wire.write(0xBE);
  Wire.write(0x08);
  Wire.write(0x00);
  Wire.endTransmission();
  delay(10);
}

bool readAHT20(float &humidityOut, float &temperatureOut) {
  Wire.beginTransmission(AHT20_ADDRESS);
  Wire.write(0xAC);
  Wire.write(0x33);
  Wire.write(0x00);

  if (Wire.endTransmission() != 0) {
    return false;
  }

  delay(80);

  Wire.requestFrom(AHT20_ADDRESS, 6);

  if (Wire.available() < 6) {
    return false;
  }

  uint8_t data[6];

  for (int i = 0; i < 6; i++) {
    data[i] = Wire.read();
  }

  uint32_t humidityRaw =
    ((uint32_t)data[1] << 12) |
    ((uint32_t)data[2] << 4)  |
    (data[3] >> 4);

  uint32_t temperatureRaw =
    ((uint32_t)(data[3] & 0x0F) << 16) |
    ((uint32_t)data[4] << 8) |
    data[5];

  humidityOut = humidityRaw * 100.0f / 1048576.0f;
  temperatureOut = temperatureRaw * 200.0f / 1048576.0f - 50.0f;

  if (humidityOut < 0.0f) {
    humidityOut = 0.0f;
  }

  if (humidityOut > 100.0f) {
    humidityOut = 100.0f;
  }

  return true;
}

// =====================================================
// SENSOR SERVICE
// =====================================================
void readSensorsNow() {
  float h;
  float t;

  if (readAHT20(h, t)) {
    humidityPct = h;
    temperatureC = t;
  }

  if (bmpOk) {
    stationPressureHpa = bmp.readPressure() / 100.0f;
  }

  seaLevelHpa = reduceToSeaLevelWMO(
    stationPressureHpa,
    temperatureC,
    humidityPct,
    altitudeM
  );
}

void serviceSensors() {
  unsigned long now = millis();

  if (now - lastSensorUpdateMs >= SENSOR_UPDATE_MS) {
    readSensorsNow();
    lastSensorUpdateMs = millis();
  }
}

// =====================================================
// WIND SERVICE
// =====================================================
void serviceWind() {
  unsigned long nowMs = millis();

  if (nowMs - lastWindBinMs < WIND_BIN_MS) {
    return;
  }

  uint32_t pulseTotalNow = getHallPulseTotal();

  uint32_t deltaPulses32 = pulseTotalNow - lastWindBinPulseTotal;
  unsigned long elapsedMsLong = nowMs - lastWindBinMs;

  lastWindBinPulseTotal = pulseTotalNow;
  lastWindBinMs = nowMs;

  uint16_t elapsedMs =
    (elapsedMsLong > 65535UL) ? 65535 : (uint16_t)elapsedMsLong;

  uint16_t pulses =
    (deltaPulses32 > 65535UL) ? 65535 : (uint16_t)deltaPulses32;

  addWindBin(elapsedMs, pulses);

  float rotorRps = 0.0f;

  if (rotorRpsFromRing(rotorRps)) {
    latestRotorRps = rotorRps;
    latestRotorRpm = rotorRps * 60.0f;
    latestWindMps = windMpsFromRotorRps(rotorRps);
  } else {
    latestRotorRps = 0.0f;
    latestRotorRpm = 0.0f;
    latestWindMps = 0.0f;
  }

  if (latestWindMps < 0.05f) {
    latestWindMps = 0.0f;
  }
}

// =====================================================
// RADIO SERVICE
// =====================================================
void sendPacket() {
  unsigned long nowMs = millis();
  unsigned long sampleMsLong = nowMs - lastTxWindSampleMs;

  if (sampleMsLong == 0) {
    sampleMsLong = 1;
  }

  lastTxWindSampleMs = nowMs;

  uint16_t sampleMs16 =
    (sampleMsLong > 65535UL) ? 65535 : (uint16_t)sampleMsLong;

  uint16_t windMpsX10 = packMpsX10(latestWindMps);

  addWindMeanSample(sampleMs16, windMpsX10);

  float meanPreview = 0.0f;

  if (meanMpsFromRecentSamples(
        WIND_MEAN_WINDOW_MS,
        WIND_MEAN_MIN_MS,
        meanPreview
      )) {
    latestMean15Mps = meanPreview;
  } else {
    latestMean15Mps = unpackMpsX10(windMpsX10);
  }

  WeatherPacket tx;

  tx.txMs = nowMs;
  tx.sampleMs = sampleMs16;
  tx.windMpsX10 = windMpsX10;
  tx.temperatureCx10 = packTempCx10(temperatureC);
  tx.humidityX10 = packUnsignedX10(humidityPct);
  tx.seaLevelHpaX10 = packUnsignedX10(seaLevelHpa);

  bool ok = radio.write(&tx, sizeof(tx));

  uint32_t pulsesNow;
  uint32_t bounceNow;
  snapshotHallCounters(pulsesNow, bounceNow);

  Serial.print("TX sampleMs=");
  Serial.print(tx.sampleMs);

  Serial.print(" wind=");
  Serial.print(unpackMpsX10(tx.windMpsX10), 1);
  Serial.print(" m/s");

  Serial.print(" rpm=");
  Serial.print(latestRotorRpm, 1);

  Serial.print(" rps=");
  Serial.print(latestRotorRps, 3);

  Serial.print(" winP=");
  Serial.print(latestWindowPulses);

  Serial.print(" winMs=");
  Serial.print(latestWindowMs);

  Serial.print(" mean15=");
  Serial.print(latestMean15Mps, 1);
  Serial.print(" m/s");

  Serial.print(" pulses=");
  Serial.print(pulsesNow);

  Serial.print(" bounce=");
  Serial.print(bounceNow);

  Serial.print(" T=");
  Serial.print(temperatureC, 1);

  Serial.print(" H=");
  Serial.print(humidityPct, 1);

  Serial.print(" Psl=");
  Serial.print(seaLevelHpa, 1);

  Serial.print(" radio=");
  Serial.println(ok ? "OK" : "FAIL");
}

void serviceRadio() {
  unsigned long now = millis();

  if (now - lastTxMs >= TX_INTERVAL_MS) {
    sendPacket();
    lastTxMs = millis();
  }
}

// =====================================================
// OLED
// =====================================================
void serviceDisplay() {
  if (!oledOk) {
    return;
  }

  unsigned long now = millis();

  if (now - lastOledUpdateMs < OLED_UPDATE_MS) {
    return;
  }

  float displayedWindMps = unpackMpsX10(packMpsX10(latestWindMps));

  display.clearDisplay();
  display.setTextSize(1);
  display.setTextColor(SSD1306_WHITE);
  display.setCursor(0, 0);

  display.print("W: ");
  display.print(displayedWindMps, 1);
  display.println(" m/s");

  display.print("RPM: ");
  display.print(latestRotorRpm, 0);
  display.println();

  display.print("M15: ");
  display.print(latestMean15Mps, 1);
  display.println(" m/s");

  display.print("T: ");
  display.print(temperatureC, 1);
  display.println(" C");

  display.print("H: ");
  display.print(humidityPct, 1);
  display.println(" %");

  display.print("P: ");
  display.print(seaLevelHpa, 1);
  display.println(" hPa");

  if (mpsToKt(latestMean15Mps) < 64.0f) {
    display.print("Scale: Bft ");
    display.println(beaufortFromMps(latestMean15Mps));
  } else {
    display.print("Scale: SS ");
    display.println(sshwsEquivalentFromMps(latestMean15Mps));
  }

  display.display();

  lastOledUpdateMs = millis();
}
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
void loop() {
  serviceWind();
  serviceRadio();
  serviceSensors();
  serviceDisplay();
}

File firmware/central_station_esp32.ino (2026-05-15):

#include <SPI.h>
#include <nRF24L01.h>
#include <RF24.h>

#include <WiFi.h>
#include "ThingSpeak.h"

#include <math.h>

// =====================================================
// USER SETTINGS
// =====================================================
const bool ENABLE_THINGSPEAK = true;

const unsigned long THINGSPEAK_REPORT_MS = 15000UL;

// Gust/peak is the highest rolling 3-second average
// inside the current 15-second report window.
const unsigned long GUST_WINDOW_MS = 3000UL;

// Serial heartbeat interval.
const unsigned long HEARTBEAT_MS = 5000UL;

// =====================================================
// nRF24
// =====================================================
// Use the receiver CE/CSN pins that worked in your radio-only test.
// These do not need to match the transmitter CE/CSN pins.
#define CE_PIN   22
#define CSN_PIN   5
#define SCK_PIN  18
#define MISO_PIN 19
#define MOSI_PIN 23

const uint8_t RADIO_CHANNEL = 76;

RF24 radio(CE_PIN, CSN_PIN);
const byte pipeAddress[6] = "RxAAA";

// =====================================================
// Wi-Fi / ThingSpeak
// =====================================================
// Put your own values here.
const char* ssid = "SSID";
const char* pass = "PASS";

unsigned long myChannelNumber = 123456;
const char* myWriteAPIKey = "API";

WiFiClient client;

// =====================================================
// COMPACT PACKET FROM TRANSMITTER
// Must match transmitter exactly.
// Fixed 14-byte payload.
// =====================================================
struct __attribute__((packed)) WeatherPacket {
  uint32_t txMs;             // transmitter millis()
  uint16_t sampleMs;         // RF sample duration
  uint16_t windMpsX10;       // wind m/s * 10
  int16_t  temperatureCx10;  // temperature C * 10
  uint16_t humidityX10;      // RH % * 10
  uint16_t seaLevelHpaX10;   // sea-level pressure hPa * 10
};

WeatherPacket rx;

// =====================================================
// GLOBAL STATE
// =====================================================
uint32_t rxPacketCount = 0;
uint32_t uploadCount = 0;

unsigned long lastHeartbeatMs = 0;

float latestTemperatureC = 20.0f;
float latestHumidityPct = 50.0f;
float latestSeaLevelHpa = 1013.25f;

// Latest received wind value.
// This should match the transmitter OLED wind value.
float latestWindMps = 0.0f;

// 15-second report accumulator.
float reportWindWeightedSum = 0.0f;  // wind m/s * milliseconds
unsigned long reportElapsedMs = 0;
float reportPeak3Mps = 0.0f;

// =====================================================
// GUST RING BUFFER
// =====================================================
const uint8_t GUST_RING_SIZE = 20;

struct WindSample {
  uint16_t sampleMs;
  uint16_t windMpsX10;
};

WindSample gustRing[GUST_RING_SIZE];
uint8_t gustWriteIndex = 0;
uint8_t gustCount = 0;

// =====================================================
// CONVERSIONS / SCALE
// =====================================================
float unpackMpsX10(uint16_t value) {
  return value / 10.0f;
}

float mpsToKt(float mps) {
  return mps * 1.94384f;
}

float mpsToKmh(float mps) {
  return mps * 3.6f;
}

uint8_t beaufortFromMps(float mps) {
  if (mps < 0.5f)  return 0;
  if (mps < 1.6f)  return 1;
  if (mps < 3.4f)  return 2;
  if (mps < 5.5f)  return 3;
  if (mps < 8.0f)  return 4;
  if (mps < 10.8f) return 5;
  if (mps < 13.9f) return 6;
  if (mps < 17.2f) return 7;
  if (mps < 20.8f) return 8;
  if (mps < 24.5f) return 9;
  if (mps < 28.5f) return 10;
  if (mps < 32.7f) return 11;
  return 12;
}

uint8_t sshwsEquivalentFromMps(float mps) {
  if (mps < 32.925f) return 0;
  if (mps < 42.700f) return 1;
  if (mps < 49.400f) return 2;
  if (mps < 58.100f) return 3;
  if (mps < 70.000f) return 4;
  return 5;
}

// =====================================================
// GUST RING HELPERS
// =====================================================
void clearGustRing() {
  gustWriteIndex = 0;
  gustCount = 0;

  for (uint8_t i = 0; i < GUST_RING_SIZE; i++) {
    gustRing[i].sampleMs = 0;
    gustRing[i].windMpsX10 = 0;
  }
}

void addGustSample(uint16_t sampleMs, uint16_t windMpsX10) {
  gustRing[gustWriteIndex].sampleMs = sampleMs;
  gustRing[gustWriteIndex].windMpsX10 = windMpsX10;

  gustWriteIndex++;

  if (gustWriteIndex >= GUST_RING_SIZE) {
    gustWriteIndex = 0;
  }

  if (gustCount < GUST_RING_SIZE) {
    gustCount++;
  }
}

bool meanMpsFromRecentGustSamples(
  unsigned long targetWindowMs,
  float &meanMpsOut
) {
  unsigned long totalMs = 0;
  float weightedSum = 0.0f;

  for (uint8_t n = 0; n < gustCount && totalMs < targetWindowMs; n++) {
    int index = (int)gustWriteIndex - 1 - n;

    while (index < 0) {
      index += GUST_RING_SIZE;
    }

    uint16_t sampleMs = gustRing[index].sampleMs;

    if (sampleMs == 0) {
      continue;
    }

    unsigned long remainingMs = targetWindowMs - totalMs;
    unsigned long usedMs = sampleMs;

    if (usedMs > remainingMs) {
      usedMs = remainingMs;
    }

    float sampleMps = unpackMpsX10(gustRing[index].windMpsX10);

    weightedSum += sampleMps * (float)usedMs;
    totalMs += usedMs;
  }

  if (totalMs < targetWindowMs || totalMs == 0) {
    meanMpsOut = 0.0f;
    return false;
  }

  meanMpsOut = weightedSum / (float)totalMs;
  return true;
}

// =====================================================
// REPORT HELPERS
// =====================================================
float reportMeanMps() {
  if (reportElapsedMs == 0) {
    return 0.0f;
  }

  return reportWindWeightedSum / (float)reportElapsedMs;
}

void resetReport() {
  reportWindWeightedSum = 0.0f;
  reportElapsedMs = 0;
  reportPeak3Mps = 0.0f;
  clearGustRing();
}

// =====================================================
// WIFI / THINGSPEAK
// =====================================================
void connectWiFi() {
  if (!ENABLE_THINGSPEAK) {
    return;
  }

  if (WiFi.status() == WL_CONNECTED) {
    return;
  }

  Serial.print("Connecting to Wi-Fi");

  WiFi.mode(WIFI_STA);
  WiFi.begin(ssid, pass);

  unsigned long startAttempt = millis();

  while (WiFi.status() != WL_CONNECTED &&
         millis() - startAttempt < 10000UL) {
    delay(500);
    Serial.print(".");
  }

  Serial.println();

  if (WiFi.status() == WL_CONNECTED) {
    Serial.print("Wi-Fi connected, IP: ");
    Serial.println(WiFi.localIP());
  } else {
    Serial.println("Wi-Fi connection failed");
  }
}
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

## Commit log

2026-05-12 Create Bill of Materials for ESP32 stations
    Added a comprehensive Bill of Materials for the portable and central ESP32 stations, detailing both minimum and optional components.
2026-05-12 Add limitations documentation for the prototype
    Document known limitations of the prototype.
2026-05-12 Revise calibration notes with current status and principles
    Updated calibration notes to include current status and wind-speed calculation principles.
2026-05-12 Update limitations.md with detailed prototype limitations
    Expanded the limitations section to include detailed descriptions of various prototype limitations, including wind-speed accuracy, sensor limitations, enclosure limitations, communication limitations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
2026-05-12 Create assembly_notes.md with assembly instructions
    Added detailed assembly notes for the portable measurement unit and anemometer assembly steps.
2026-05-12 Revise Bill of Materials for ESP32 prototype
    Updated the Bill of Materials to include minimum and optional components for the ESP32 weather station prototype, along with detailed notes on each component's use.
2026-05-12 Revise Bill of Materials with detailed components
    Updated the Bill of Materials to include detailed descriptions for components, organized sections for clarity, and added optional future improvements.
2026-05-12 Update bill of materials by removing introductory notes
    Removed introductory notes about the components and firmware configuration for the prototype.
2026-05-12 Clean up bill_of_materials.md
    Removed unnecessary lines from the Bill of Materials.
2026-05-12 Revise bill of materials for ESP32 weather station
    Updated the bill of materials for the portable ESP32-based weather station, enhancing clarity and detail in component descriptions and organization.
2026-05-12 Update bill of materials by removing sensor note
    Removed note about firmware configuration for sensors.
2026-05-12 Update bill of materials by removing notes
    Removed notes for AHT20 and KY-003 sensor modules.
2026-05-12 Remove notes for optional converters in BOM
    Removed notes for optional MP1584EN and MT3608 converters.
2026-05-12 Initialize wind sampling and sensor settings
    Added includes and defined constants for wind sampling and environmental sensors.
2026-05-12 Update sensor model from DHT22 to AHT22
2026-05-12 Fix typo in sensor name from DHT22 to AHT22
2026-05-12 Update assembly notes for ESP32 weather prototype
    Expanded assembly notes for the ESP32-based weather monitoring prototype, detailing system overview, components, assembly steps, pinouts, and operational procedures.
2026-05-12 Revise assembly notes for wind speed and debounce filter
    Updated wind speed calculation notes and added debounce filter constants.
2026-05-12 Revise limitations documentation for clarity and detail
    Updated limitations section with additional details on algorithm calibration, pressure correction, and online publication dependencies. Improved clarity and added new subsections for pressure correction and online publication limitations.
2026-05-12 Rename Hurricane Wind Device.f3d to portable_weather_station_cad_complete.f3d
    [Hurricane Wind Device.f3d, portable_weather_station_cad_complete.f3d]
2026-05-12 Add link to printables model 1719175
2026-05-12 Add placeholder file for printable parts
2026-05-12 Add pinout documentation for ESP32 weather station
    Document the pinout and wiring for the ESP32-based portable weather monitoring prototype, including details for the portable and central stations, sensors, and communication modules.
2026-05-13 Revise bill of materials for weather monitoring system
    Updated the bill of materials for the ESP32-based weather monitoring system, including changes to component descriptions, quantities, and notes for clarity and accuracy.
2026-05-13 Revise wind-speed algorithm notes and edge gate removal
    Updated assembly notes to reflect changes in wind-speed algorithm and removed obsolete edge gate description.
2026-05-13 Update power limitations section in limitations.md
    Added details about the power switch and potential back-powering issues.
2026-05-13 Add comment to Wire.begin for clarity
2026-05-13 Update bill of materials by removing notes section
    Removed notes regarding wiring, screw lengths, and prototype intentions.
2026-05-13 Fix formatting issue in assembly notes
2026-05-15 Refactor ESP32 firmware for weather data processing
2026-05-15 Add links to printables and ThingSpeak
    Added links to printables and ThingSpeak for reference.
2026-05-15 Remove txPacketCount tracking and logging
    Removed txPacketCount variable and related print statements.
2026-05-15 Update sensor model from AHT22 to AHT20
